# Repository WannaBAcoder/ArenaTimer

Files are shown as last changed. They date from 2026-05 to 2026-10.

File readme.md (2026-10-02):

# ⏱️ Event Match Timer & Lockout System

An open-source, ESP32-based event and match timer platform featuring wireless remote integration, with web interface.

---

## 🚀 Getting Started

### 1. Hardware Orientation & Powering
* **Orientation Flexibility:** The timer can be configured to operate in either horizontal orientation. If your mounting or power cable strategy requires it, you can flip the included hanging bracket to the opposite side and enable **Invert Display** in the web settings to route the power cable from above.
* **Power Requirements:** Connect the timer using the provided power supply. 
> ⚠️ **CRITICAL:** Only use **5V** power supplies capable of delivering at least **60W**. Applying a voltage higher than 5V will **permanently damage** the hardware.

### 2. Initial Wi-Fi & Web UI Setup
1. **Boot Sequence:** Upon power-up, the display initializes with dashes (`--:--`) and the border will blink, indicating it is attempting to connect to the last saved Wi-Fi network.
2. **Access Point (AP) Mode:** If the network is unavailable (or during first-time setup), the timer switches to AP mode, broadcasting its own network:
   * **SSID:** `TimerSetup`
   * **Password:** `12345678`
3. **Connecting to the UI:** * Connect your phone, tablet, or computer to the `TimerSetup` network.
   * Locate the timer's IP address in your device's network connection settings (this process varies by operating system).
   * Open a web browser and enter the IP address to access the control interface.

<p align="center">
  Web Control Interface Dashboard
</p>

*Note: The local AP interface is identical to the network interface. If no external Wi-Fi network is available at your venue, you can run the timer in this standalone mode completely offline.*

4. **Station Mode (Optional):** To connect the timer to an existing venue Wi-Fi network, use the configuration section at the bottom of the webpage to save your local **SSID** and **Password**.

<p align="center">
  Wireless Remotes Layout
</p>

---

## ⚙️ Configuration & Features

### 🎮 Wireless Remotes & Pairing
The system supports three battery-powered wireless remotes: **one Main Controller** and **two Driver Ready/Tap-Out buttons** (Red vs. Blue).

<p align="center">
  Wireless Remotes Layout
</p>

* **Pairing Procedure:** Remotes must be paired before deployment. Click **Pair Remote** in the Web UI to enter binding mode, turn on the remote, and press any button. The timer will automatically exit binding mode, and the Web UI status will update to `Paired`.  Repeat independently for each remote.
  * *Pairing Timeout:* Binding mode automatically cancels itself after 15 seconds if no remote responds (with a live countdown shown on screen), rather than hanging indefinitely until a reboot.
* **Driver Ready Lockout:** Enabling the `Require Driver Ready` checkbox prevents a match from starting until both driver remotes register a "Ready" state - the **Start** button itself grays out while waiting, and the ready state for each side is shown directly under the countdown.
  * *Visual Indicators:* The physical white border indicates overall readiness. Individual Red/Blue illumination confirms when each respective driver has ready-ed up.
* **Tap-Out Functionality:** Even if the pre-match lockout is disabled, the driver remotes function by default as tap-out indicators. Pressing them during a match triggers a unique tap-out animation and audio effect (can be toggled off via the checkbox).

<p align="center">
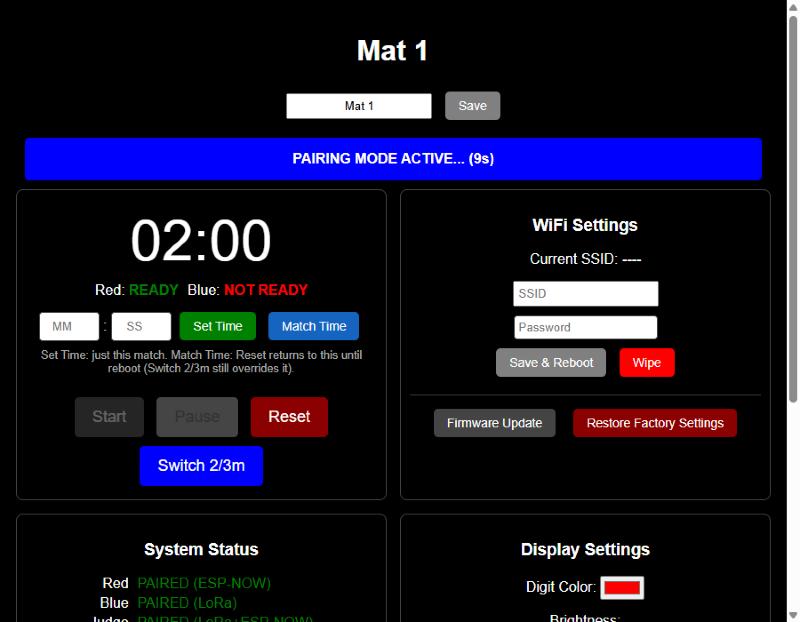
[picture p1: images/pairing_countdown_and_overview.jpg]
Pairing countdown, ready status, and per-timer naming
  
</p>

### 📻 ESP-NOW and LoRa Remotes, Side by Side
Newer timer boards carry an onboard LoRa radio alongside the original ESP-NOW remote support - both run **at the same time, in the same firmware image**. That means a single timer can have, say, Red paired to an older ESP-NOW remote while Blue and Judge are paired to newer LoRa remotes, so a LoRa-capable board can go into service before every remote in the field is replaced.

* **Per-Role Binding:** Each of Red, Blue, and Judge is paired independently, and the System Status panel shows exactly which radio each one is bound through - `PAIRED (ESP-NOW)`, `PAIRED (LoRa)`, or `PAIRED (LoRa+ESP-NOW)` if the same role has been bound on both.
* **Automatic Hardware Detection:** On boards without the LoRa radio installed, the firmware detects its absence at boot (shown as `LoRa radio: Not detected`) and simply runs ESP-NOW only, rather than wasting startup time retrying a radio that isn't there.

<p align="center">
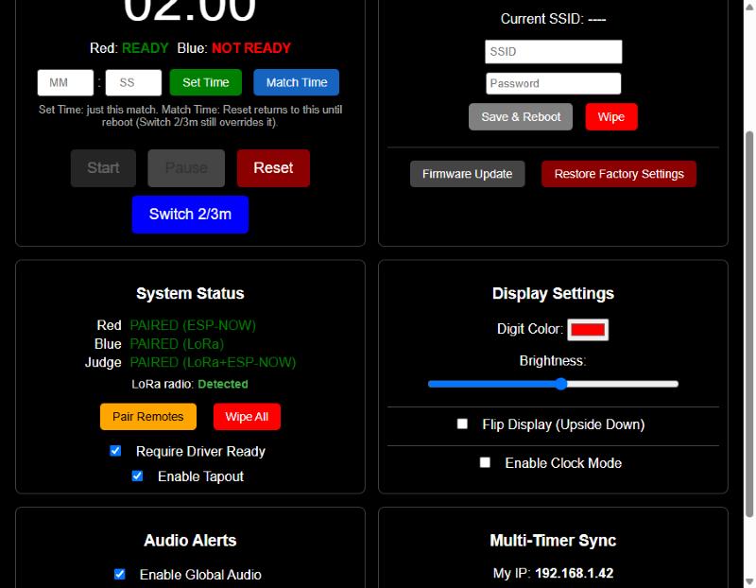
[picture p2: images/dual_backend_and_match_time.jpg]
Dual ESP-NOW/LoRa pairing status, Match Time, and WiFi management
  
</p>

### 🔗 Multi-Timer Sync (Web-Based)
Running several mats off one set of remotes already works by pairing the same remote to each timer directly (above) - but for anything triggered from the **web page** (start/pause/reset, time-select, colors, brightness, audio, ready/tapout settings), pair two timers together over WiFi so clicking a button on one applies to both.

* **Setup:** Open the **Multi-Timer Sync** panel, enter the other timer's local IP address (shown on its own page as `My IP`), and click **Sync**. Everything that timer currently has configured pushes over immediately, so both units start in agreement instead of drifting until the next change.
* **What Syncs:** Match control, match time, display color/brightness/flip, audio settings, ready-required, tap-out, and clock mode. Remote button presses are *not* relayed this way - they already reach every timer that remote is directly paired to, with no extra setup needed.
* **One-Directional by Default:** Sync only pushes outward from whichever timer's web page you clicked on - pair both timers to each other's IP if you want either one to be able to drive the other.
* **Naming Timers:** Give each unit a short label (e.g. "Mat 1") at the top of its page - shown in the browser tab too - so it's obvious which page you're looking at when several are open side by side.

### ⏱️ Match Time vs. Set Time
Two different buttons next to the manual MM:SS entry handle two different needs:

* **Set Time:** A one-off override for just the upcoming match. Pressing **Reset** afterward falls back to whatever the standing default already was (the 2/3-minute preset, or a previously-set Match Time).
* **Match Time:** Sets a new standing default - **Reset** keeps returning to this duration until the unit reboots (it isn't saved permanently, so a custom one-off event length doesn't silently become the new default forever). The **Switch 2/3m** button still overrides it either way.

### 🕐 Clock Mode
Toggle **Enable Clock Mode** (in Display Settings) to repurpose the digit display as a wall clock when the timer is idle between matches. The web page itself keeps showing whatever match time was last active (dimmed, since it isn't live) - the physical display is what shows the actual time.

### 🔊 Audio Options
* **Global Toggle:** Easily enable or disable all system audio via the web panel.
* **Output Routing:** Switch between the onboard piezo beeper or a dedicated **relay output** used to switch larger external horn circuits, PA systems, or specialized lighting.
* **Attention Horn:** The Main Controller features a dedicated button to manually trigger the sound effects to grab the attention of competitors or spectators.

### 🔒 Operational Lockout
To prevent accidental mid-match disruption, most configuration options, adjustments, and web buttons are **automatically disabled** while the timer is actively running.

---

## 🛠️ Assembly Process (Electronics Kits)

For users assembling the hardware from the DIY electronics kits, follow this general framework. Refer to the project `BOM.md` for exact hardware sizing, screw counts, and component sourcing links.

### 1. 3D Printed Frame Selection
Choose the frame variant that best fits your 3D printer's build volume:
* **Small Printers:** Cut down to fit standard build plates. Requires more assembly hardware and time but maximizes accessibility.
* **Medium Printers (H2s/H2d Optimized):** A balanced approach featuring lower part counts and optimized print times.
* **Large Printers:** Designed specifically for large-format platforms like the *Elegoo Orange Storm Giga*. 

### 2. Print Settings & Materials
* **Main Frame:** Print in **PETG** for superior mechanical strength and thermal resilience during high-temperature transport or storage.
  * **Walls:** 4–6 perimeters
  * **Infill:** 15–25% Gyroid
* **Lenses:** All frame variations share the same lens files. Print them with enough top/bottom layers to ensure the front face prints **completely solid** to optimize light diffusion and visual clarity.

---

## 🧠 Advanced Development & Limitations

### 📡 RF Limitations & Best Practices
The timer utilizes an **ESP32** module with a printed trace antenna; remotes utilize **ESP8266** modules over ESP-NOW, or on newer timer boards, dedicated **LoRa** radios (see [ESP-NOW and LoRa Remotes, Side by Side](#-esp-now-and-lora-remotes-side-by-side) above) - both with printed antennas.
* **Range & Interference:** While highly reliable in tested arena layouts (e.g., SEMO), performance can degrade at extreme distances or in environments experiencing heavy 2.4 GHz spectrum congestion (crowded Wi-Fi, heavy radio traffic).
* **Upgrades:** If your venue demands extreme range, the hardware can be modified to use variants featuring external SMA antennas. Reach out if you need assistance engineering a solution.
* **Running Multiple Timers:** Pair a single set of remotes to multiple timers by repeating the pairing process on each one (above), and/or bind timers to each other for web-triggered actions - see [Multi-Timer Sync](#-multi-timer-sync-web-based) above.

### 💻 Firmware Upgrades & Exposed I/O
* **Over-The-Air (OTA) Updates:** Firmware updates can be flashed seamlessly without opening the enclosure. Navigate to `http://<your-timer-ip>/update` to access the **ElegantOTA** interface, where you can drag-and-drop compiled `.bin` updates.
* **Restore Factory Settings:** A dedicated button wipes all remotes, WiFi credentials, sync target, and display/audio settings in one step, then reboots - useful for repurposing a unit or ruling out a stale setting during troubleshooting. WiFi credentials alone can also be wiped independently (`Wipe`, next to Save & Reboot) without touching anything else.
* **Hardware Expansion:** Additional I/O pins are deliberately exposed near the internal ESP32 module. Advanced users can open the case and solder directly to these lines to integrate custom addressable LED strips, sensors, or physical inputs.

### ⚡ ESD Precautions & LED Repair
> ⚡ **CAUTION:** The internal PCBs contain components sensitive to Electrostatic Discharge (ESD). Handle bare board assemblies with care during assembly or modifications.

* **Common Failure Mode:** If an ESD event occurs, a single addressable LED in the display chain may burn out. Because the LEDs are wired in series, **if one LED fails, all subsequent data down the chain is blocked**, causing the rest of the display past that point to drop out. 
* **Support:** If you experience an LED failure during assembly or firmware hacking, reach out—these are repairable, and I can guide you through jumping or replacing the compromised pixel. Note that failures have only occurred during loose bench development; fully enclosed units have proven resilient during regular live event usage.

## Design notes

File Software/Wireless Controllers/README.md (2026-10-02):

# Wireless Controllers

Remote-side firmware for the battle timer's two supported remote protocols.
A remote is one or the other - never both, and nothing else:

- **`ESPNOW_Remote/`** - genuine ESP-NOW (ESP8266, `espnow.h`), each a
  separate PlatformIO project (not variants of one shared source):
  - `controller/` - the Judge remote, 5 buttons.
  - `ready_remote/` - the Red/Blue "driver ready" remote, 1 button. Set
    `DEV_TYPE` to `"RedReady"` or `"BlueReady"` per physical unit before
    flashing. Recovered from git history (commit f13efa9) after a later
    commit overwrote this same filename with an unrelated LLCC68/RadioLib
    design that was never ESP-NOW at all.

  Both received by the timer's `espnowRemotes.cpp`.

- **`TimerRemote/`** - the correct, current LoRa remote (STM32 + RA-08H
  radio module, talks to the timer's own RA-08H over actual LoRa RF, not
  WiFi). Received by the timer's `loraRemotes.cpp`. This is the one to
  build on for any new LoRa remote work.

- **`_archive/`** - superseded prototypes, kept for reference only. Not
  wired up to anything current and safe to delete outright once nobody
  needs to look back at them:
  - `timer_wifi_logic/` - an early draft of the *timer's* own ESP-NOW
    receive logic, predating and superseded by `Software/main`'s
    `espnowRemotes.cpp`. Not a remote.

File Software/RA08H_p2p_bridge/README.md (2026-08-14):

# RA-08H P2P Bridge Firmware

Replacement firmware for the RA-08H (ASR6601) LoRa modules on the ArenaTimer
boards. The stock Ai-Thinker firmware is **LoRaWAN-only** (`release/v1.3.4
LoRaWAN for US915`) and has no device-to-device path — LoRaWAN requires a
gateway and network server, so it can't be used for remote-to-timer links.
This firmware replaces it with raw LoRa P2P.

It exposes the same text protocol the host code already speaks, so
`TimerRemote/src/radio.cpp` and `Software/main/src/loraRemotes.cpp` need no
changes:

```
host -> radio:  AT+TEST=TXLRPKT,"<HEX>"\n
radio -> host:  OK                                     (accepted, transmitting)
                ERROR                                  (bad command or payload)
                +TEST: RXLRPKT,"<HEX>",<rssi>,<snr>    (packet received)
```

Identical on both boards — which side is "remote" vs "timer" is purely a
host-MCU concern.

## Runtime RF config

TX power, spreading factor, bandwidth, and coding rate are adjustable at
runtime, so range/power tuning doesn't require reflashing the radio — only
the host MCU (much cheaper to reflash via SWD, no BOOT-jumper dance needed):

```
host -> radio:  AT+RFCFG=<power>,<sf>,<bw>,<cr>\n
radio -> host:  OK                                (applied)
                ERROR                              (out of range or malformed)

host -> radio:  AT+RFCFG?\n
radio -> host:  +RFCFG: <power>,<sf>,<bw>,<cr>
                OK
```

| field | range | meaning |
|---|---|---|
| power | -3 to 22 | dBm (SX1262's actual max is 22, not the 14 the defaults use) |
| sf | 5 to 12 | spreading factor |
| bw | 0, 1, 2 | 0 = 125 kHz, 1 = 250 kHz, 2 = 500 kHz |
| cr | 1 to 4 | coding rate, 1 = 4/5 ... 4 = 4/8 |

**Not persisted** — RFCFG changes are RAM-only and reset to the `DEFAULT_*`
values in `main.c` on every power-up/reset. The host is expected to re-send
its desired config (from its own persistent settings) after every boot; see
`TimerRemote/src/radio.cpp`'s `radioInit()` and `Software/main/src/loraRemotes.cpp`'s
`loraInit()` for where that happens.

Spreading factor and bandwidth must match on both ends of a link — the two
radios can't demodulate each other's packets otherwise. TX power is
one-sided and only needs to change on the transmitting radio.

## Runtime RX mode

Also adjustable at runtime: whether the radio sits in continuous receive or
sleeps between transmits. A LoRa remote in this system only ever sends
button presses and never needs to receive, so leaving it in continuous RX —
the SX1262's most power-hungry state — burns battery for no functional
benefit. The timer needs the opposite: it must always be listening.

```
host -> radio:  AT+RXMODE=<mode>\n
radio -> host:  OK                                (applied)
                ERROR                              (out of range or malformed)

host -> radio:  AT+RXMODE?\n
radio -> host:  +RXMODE: <mode>
                OK
```

| mode | meaning |
|---|---|
| 0 | TX-only — radio sleeps between sends, wakes automatically to transmit |
| 1 | continuous RX (default) — always listening, as before this command existed |

Same as RFCFG: not persisted, RAM-only, reset to `DEFAULT_RX_MODE` on every
power-up. Waking from sleep to transmit needs no special handling — any SPI
transaction wakes the SX1262 automatically (a documented hardware feature),
and this firmware already relies on that exact transition after every
completed TX regardless of RX mode.

Both host projects' `rfConfig.h` currently default to `RF_RX_MODE = 1`
(continuous, matching pre-RXMODE behavior) even on remotes, until TX-only
mode has been measured and validated on real hardware. Flip to `0` on a
remote's `rfConfig.h` once confirmed worthwhile, and reflash just that
board's STM32/ESP32 — no radio reflash needed, same firmware image runs
either mode.

## Radio configuration (power-on defaults)

| setting | value |
|---|---|
| frequency | 915 MHz (US915) |
| spreading factor | SF7 |
| bandwidth | 125 kHz |
| coding rate | 4/5 |
| TX power | 14 dBm |
| preamble | 8 symbols |
| max payload | 32 bytes |

## UART wiring

Two different UART peripherals are used, matching how the stock firmware did
it and matching the board's existing traces:

- **LPUART RX** — GPIOD pin 12 (`LPRXD`/IO60), commands arrive from the host MCU
- **UART0 TX** — GPIOB pin 1 (`TXD`/IO17), responses go out; shared with the
  flash/debug port

Both at **9600 baud**. This is a hardware limit, not a preference: the AT
interface runs on the LPUART, whose baud rate cannot exceed 9600.

## Building

Needs the Ai-Thinker SDK (`Ai-Thinker-Open/Ai-Thinker-LoRaWAN-Ra-08`). Drop
this directory in as `projects/ASR6601CB-EVAL/examples/lora/p2p_bridge`, then
from Git Bash:

```bash
export TREMO_SDK_PATH=/path/to/Ai-Thinker-LoRaWAN-Ra-08
export PATH="$PATH:$HOME/.platformio/packages/toolchain-gccarmnoneeabi/bin:/c/ProgramData/chocolatey/bin"
make
```

No WSL required — PlatformIO's bundled `toolchain-gccarmnoneeabi` (xPack GNU
Arm Embedded GCC) plus chocolatey's `make` build it natively on Windows, which
is what the SDK's own `envsetup.sh` falls back to when `arm-none-eabi-gcc` is
already on PATH.

A prebuilt `p2p_bridge.bin` is included.

## Flashing

The RA-08H enters download mode when **BOOT (IO2, module pin 15) is high at
reset**. On these boards that pad is tied to GND by the JP1 solder jumper, so:

1. Cut the JP1 bridge, wire that pad to VCC (needs a pullup — a bare floating
   wire is not enough).
2. Power-cycle the board.
3. Flash — the adapter's RX taps the existing `TXD` trace, no bodge needed:

```bash
python $TREMO_SDK_PATH/build/scripts/tremo_loader.py -p COM16 -b 921600 flash 0x08000000 p2p_bridge.bin
```

4. Return BOOT to GND and power-cycle again for normal boot.

Future board revisions should provision a proper programming header — doing
this by hand does not scale past a handful of boards.

## Debugging note

**Start the serial listener _before_ power-cycling the board.** This firmware
prints its boot log once and then goes quiet, so a listener attached a few
seconds later sees nothing and looks identical to a dead board. That false
signal cost a long debugging detour; `uart_probe`-style firmware that prints
in a loop is not affected, which makes the contrast misleading.

Expected boot output:

```
=== p2p_bridge boot ===
CKPT: xo32k enabled
... (per-step init checkpoints) ...
CKPT: rf config applied (power=14 sf=7 bw=0 cr=1)
READY
```

`READY` means the radio is initialized and listening.

## Verified

Bench test, two boards a few inches apart, 3/3 packets received intact at
RSSI −5 dBm / SNR 13 dB.

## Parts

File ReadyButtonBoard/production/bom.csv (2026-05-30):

Designator | Footprint | Quantity | Value | LCSC Part #
D1 | 0603 | 1 | Red | C2286
J1, J2 | PinSocket_1x08_P2.54mm_Vertical | 2 | Conn_01x08_Socket | C42431840
J9 | 2060-452_998-404 | 1 | WAGO | C2765055
R1 | 0603 | 1 | 470 | C23179
SW1 | SW_PUSH-12mm | 1 | START | C2888699

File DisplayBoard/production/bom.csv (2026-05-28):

Designator | Footprint | Quantity | Value | LCSC Part #
C1, C2, C3, C4, C5, C6, C7 | 0402 | 7 | 100nF | C14663
D1, D10, D11, D112, D113, D114, D115, D116, D117, D118, D12, D13, D14, D15, D154, D155, D156, D157, D158, D159, D16, D160, D17, D18, D19, D2, D20, D21, D22, D23, D238, D239, D24, D240, D241, D242, D243, D244, D245, D246, D247, D248, D249, D25, D250, D251, D252, D253, D254, D255, D256, D257, D258, D259, D26, D260, D261, D262, D263, D264, D265, D266, D267, D268, D269, D27, D270, D271, D272, D273, D274, D275, D276, D277, D278, D279, D28, D280, D281, D282, D283, D284, D285, D286, D287, D288, D289, D29, D290, D291, D292, D293, D294, D295, D296, D297, D298, D299, D3, D30, D300, D301, D302, D303, D304, D305, D306, D307, D308, D309, D31, D310, D311, D312, D313, D314, D315, D316, D317, D318, D319, D32, D320, D321, D322, D323, D324, D325, D326, D327, D328, D329, D33, D330, D331, D332, D333, D334, D335, D336, D337, D338, D339, D34, D340, D341, D342, D35, D36, D37, D38, D4, D5, D6, D7, D70, D71, D72, D73, D74, D75, D76, D77, D78, D79, D8, D80, D81, D82, D83, D9 | LED_WS2812B_PLCC4_5.0x5.0mm_P3.2mm | 171 | WS2812B | C2843785
D40 | D_SMA | 1 | 1N1007, SMA | C727081
D41 | D_SOD-323 | 1 | 1N4148WS, SOD323 | C2128
J1 | JST_EH_S2B-EH_1x02_P2.50mm_Horizontal | 1 | Blue ready-up | C19271377
J10 | JST_EH_S2B-EH_1x02_P2.50mm_Horizontal | 1 | Red ready-up | C19271377
J13, J14 | 2060-452_998-404 | 2 | WAGO | C2765055
J15, J16 | PinSocket_1x15_P2.54mm_Vertical | 2 | Conn_01x15_Socket | C124408
J2 | PinSocket_1x02_P2.54mm_Horizontal | 1 | Conn_01x02_Socket | C2897384
J3 | PinHeader_1x02_P2.54mm_Horizontal | 1 | Conn_01x02_Pin | C492410
J4 | PinHeader_1x04_P2.54mm_Horizontal | 1 | GND | C492412
J5 | PinHeader_1x04_P2.54mm_Horizontal | 1 | 5V | C492412
J6 | PinSocket_1x04_P2.54mm_Horizontal | 1 | GND | C2897386
J7 | PinSocket_1x04_P2.54mm_Horizontal | 1 | 5V | C2897386
J9 | JST_EH_S6B-EH_1x06_P2.50mm_Horizontal | 1 | Conn_01x06_Pin | C157919
Q1, Q2 | SOT-323_SC-70 | 2 | BSS138 | C5224267
R10, R2 | 0402 | 2 | 100K | C25530
R3, R4, R5, R6, R7, R8, R9 | 0402 | 7 | 10k | C25744

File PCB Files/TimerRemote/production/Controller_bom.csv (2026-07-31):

Designator | Footprint | Quantity | Value | LCSC Part #
C16 | 0402 | 1 | C | DNU
C17 | 0402 | 1 | 4.7pF | C1569
C18 | 0402 | 1 | 2pF | C1558
C24, C27 | 0402 | 2 | 1uF, 25V | C52923
C3, C5 | 0603 | 2 | 10uF, 25V | C96446
C4, C6, C8 | 0402 | 3 | 100nF | C1525
J13 | 2060-452_998-404 | 1 | WAGO | C2765055
J2 | Harwin_M20-89006xx_1x06_P2.54mm_Horizontal | 1 | PROG | C20610215
J3 | PinHeader_1x03_P2.54mm_Vertical | 1 | VBAT
J5 | PinHeader_1x03_P2.54mm_Vertical | 1 | GND
JP1 | SolderJumper-2_P1.3mm_Bridged_RoundedPad1.0x1.5mm | 1 | Jumper_2_Bridged
R19 | 0402 | 1 | 10k, 1% | C25744
R5, R6 | 0402 | 2 | 0 ohm | C17168
SW1 | SW_Push_1P1T_NO_CK_PTS125Sx43SMTR | 1 | START | C18186488
SW2 | SW_Push_1P1T_NO_CK_PTS125Sx43SMTR | 1 | PAUSE | C18186488
SW3 | SW_Push_1P1T_NO_CK_PTS125Sx43SMTR | 1 | RESET | C18186488
SW4 | SW_Push_1P1T_NO_CK_PTS125Sx43SMTR | 1 | TIME_SEL | C18186488
SW5, SW6 | SW_Push_1P1T_NO_CK_PTS125Sx43SMTR | 2 | BUZZER | C18186488
SW7 | SW_Slide_SPDT_Angled_CK_OS102011MA1Q | 1 | SW_SPDT | C136722
SW8 | SW_Push_1P1T_XKB_TS-1187A | 1 | SW_Push | C318884
U1 | RA-08H | 1 | Ai-Thinker RA-08H | C2991932
U2 | LQFP-32_7x7mm_P0.8mm | 1 | STM32G030K6Tx | C529331
U5 | SOT-23-5 | 1 | AP2112K-3.3 | C51118

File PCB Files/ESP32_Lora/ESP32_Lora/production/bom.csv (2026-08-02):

Designator | Footprint | Quantity | Value | LCSC Part #
C10, C11, C12, C13, C6, C8 | 0402 | 6 | 100nF | C1525
C14, C15, C5, C7, C9 | 0603 | 5 | 10uF, 25V | C96446
C16 | 0402 | 1 | C | DNU
C17 | 0402 | 1 | 4.7pF | C1569
C18 | 0402 | 1 | 2pF | C1558
D1 | D_SOD-323 | 1 | BAT760-7 | C124187
D10 | 0603 | 1 | LED, Red | C965799
D12 | 0603 | 1 | LED, Blue | C965807
J114 | USB_C_Receptacle_GCT_USB4105-xx-A_16P_TopMnt_Horizontal | 1 | USB_C_Receptacle_USB2.0_14P | C309347
J15, J16 | PinHeader_1x15_P2.54mm_Vertical | 2 | Conn_01x15_Socket | C7501269
J2 | U.FL_Molex_MCRF_73412-0110_Vertical | 1 | Conn_Coaxial_Small | C2987682
JP1 | SolderJumper-2_P1.3mm_Bridged_RoundedPad1.0x1.5mm | 1 | Jumper_2_Bridged
Q1, Q2 | SOT-23 | 2 | SS8050 | C2834467
R10, R14, R15, R16, R17 | 0402 | 5 | 10k | C25744
R104, R105 | 0201 | 2 | 5.1K | C367648
R11 | 0402 | 1 | 47.5K (1%) | C2930010
R12, R18 | 0402 | 2 | 470, 1% | C25117
R13 | 0402 | 1 | 22.1K (1%) | C43473
R5, R6 | 0402 | 2 | 0 ohm | C17168
SW1, SW2 | SW_Push_SPST_NO_Alps_SKRK | 2 | SW_Push | C115357
U1 | RA-08H | 1 | Ai-Thinker RA-08H | C2991932
U3 | QFN-28-1EP_5x5mm_P0.5mm_EP3.35x3.35mm | 1 | CP2102N-Axx-xQFN28 | C964632
U4 | ESP32-WROOM-32UE | 1 | ESP32-WROOM-32UE | C701344
U5 | SOT-23-5 | 1 | AP2112K-3.3 | C51118
U902 | SOT-143 | 1 | CM1213A−02Sx | C19268160

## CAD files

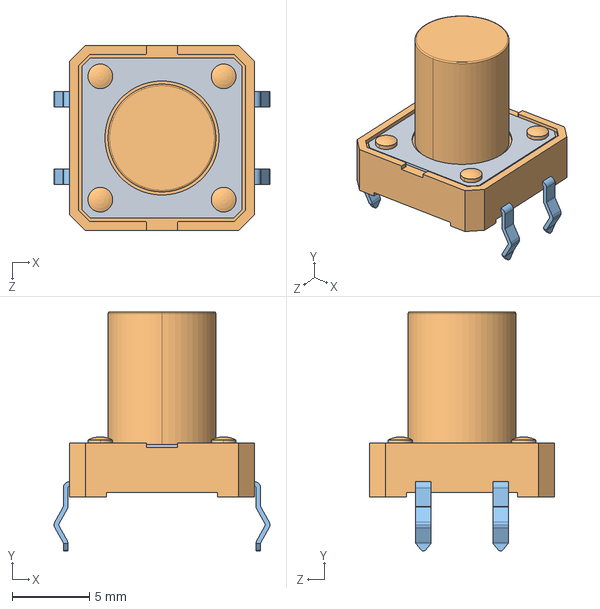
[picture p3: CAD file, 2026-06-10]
ButtonBoard/Same_Sky_TS14-1212-120-BK-260-SCR-D.step
14.0 x 15.5 x 12.0 mm

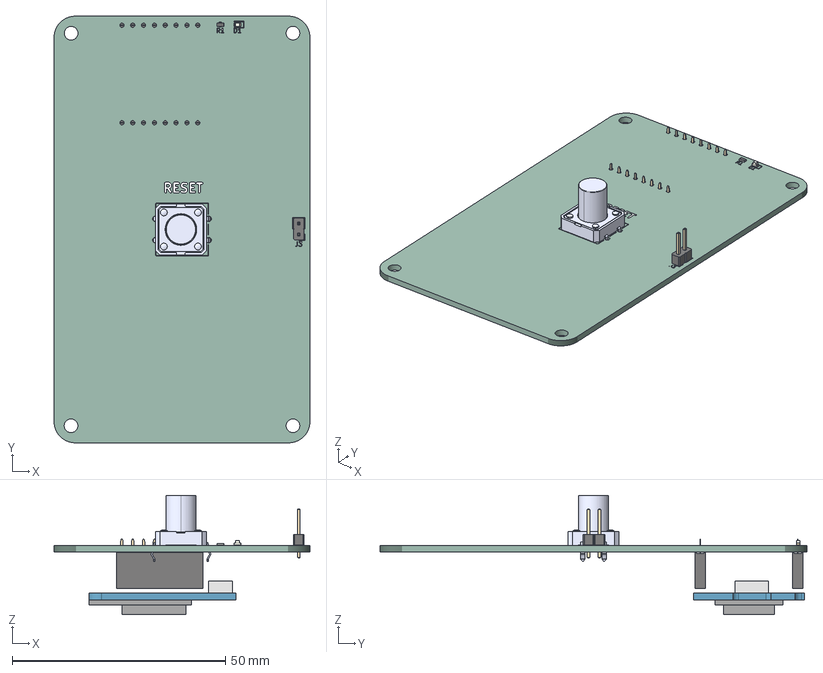
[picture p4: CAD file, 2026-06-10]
ReadyButtonBoard/ReadyButtonBoard.step
60.0 x 100.0 x 28.0 mm
PinHeader_1x02_P254mm_Vertical
LED_0603_1608Metric
CUI_DEVICES_TS14-1212-120-BK-260-SCR-D
R_0603_1608Metric
PinSocket_1x08_P2.54mm_Vertical x 2
wemos_d1_mini_light
ReadyButtonBoard_silkscreen x 2
ReadyButtonBoard_PCB

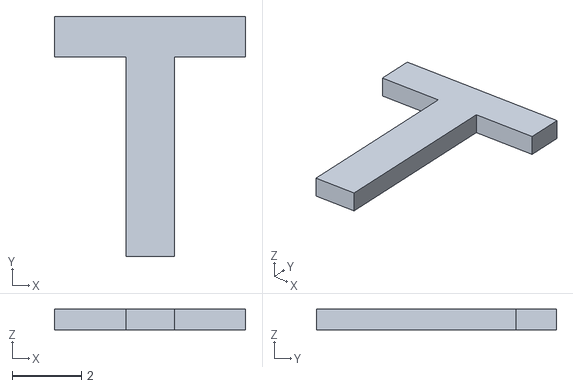
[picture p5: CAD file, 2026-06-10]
STLs/TimerPrints/Button Cases/ControllerHousing/ControllerHousing_ButtonBoard v22_Body22.stl
5.52 x 6.94 x 0.6

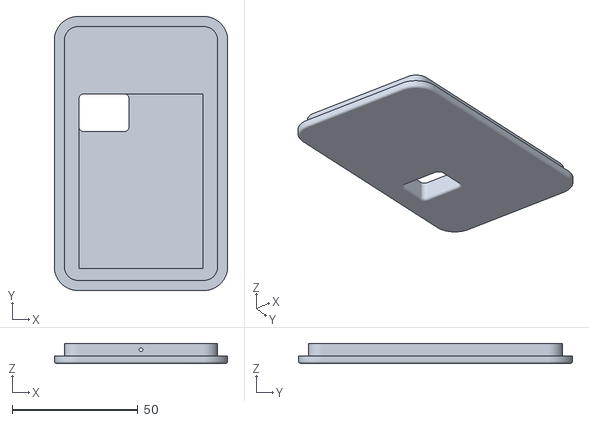
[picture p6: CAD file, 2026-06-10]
STLs/TimerPrints/Button Cases/ReadyButtonHousing/ReadyButtonHousing_LargerReadyButton v7_bottom_cover.stl
69.0 x 109.0 x 8.00

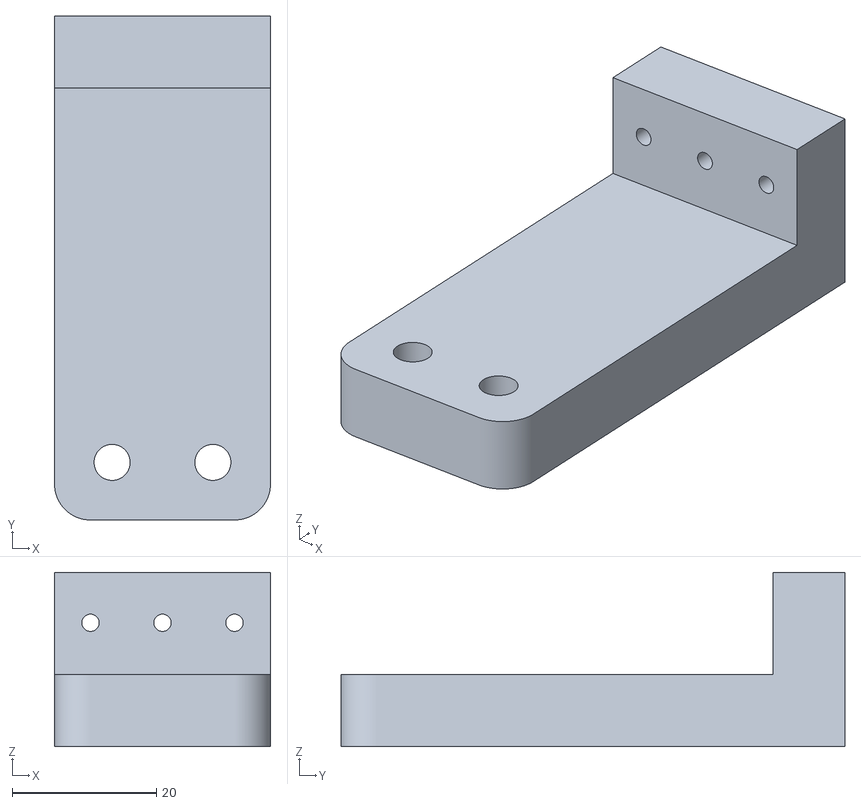
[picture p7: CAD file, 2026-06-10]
STLs/TimerPrints/Multi-Piece Housing/Hanging_mount.stl
30.0 x 70.0 x 24.2

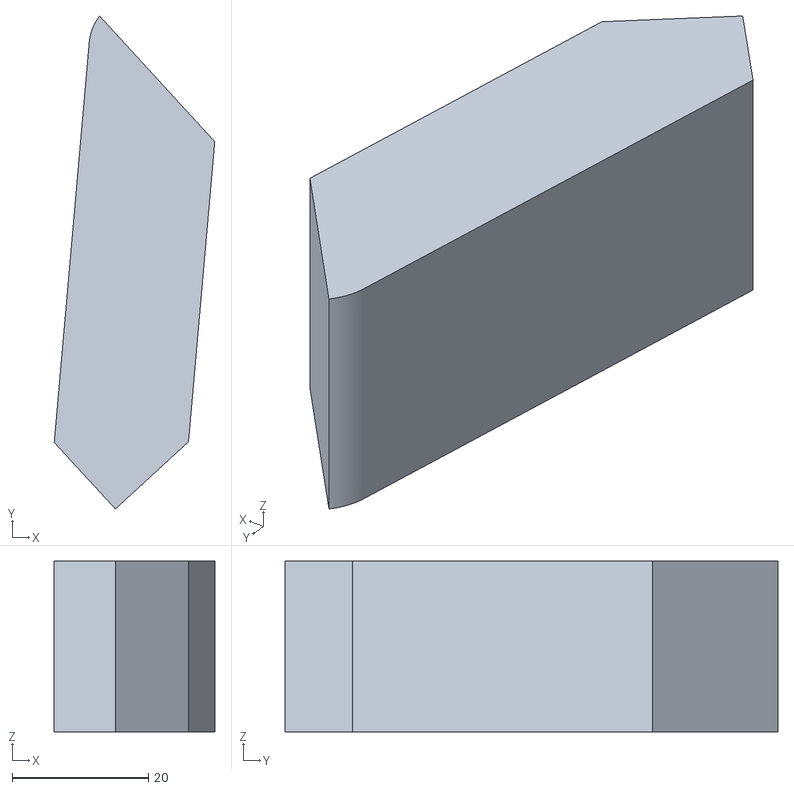
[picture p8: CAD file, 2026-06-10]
STLs/TimerPrints/Multi-Piece Housing/Lenses/seg_c.stl
23.5 x 72.3 x 25.0

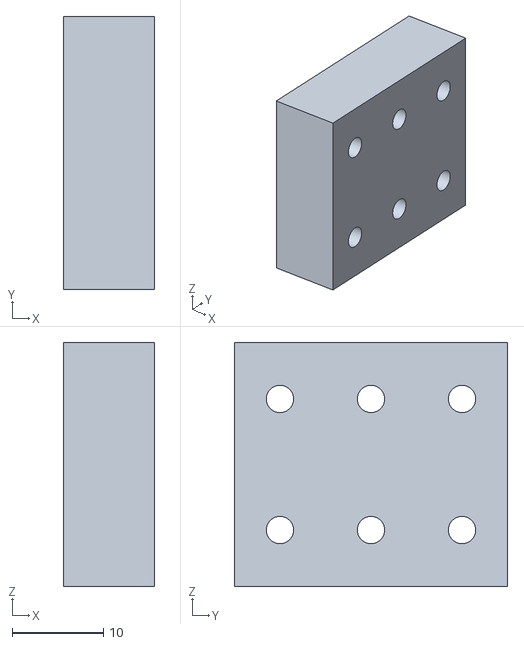
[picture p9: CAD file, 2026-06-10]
STLs/TimerPrints/Single Piece Housing/Double_sided_mount.stl
10.00 x 30.0 x 26.8

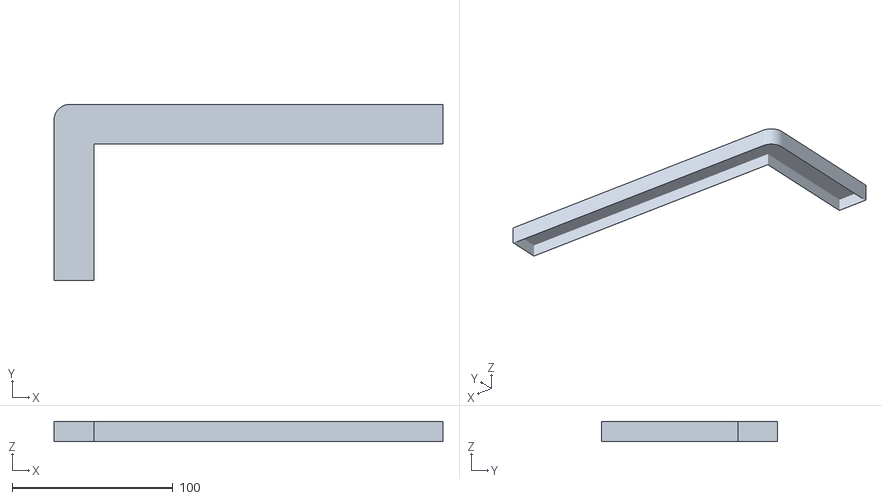
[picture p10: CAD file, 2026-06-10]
STLs/TimerPrints/Single Piece Housing/Lenses/bottom_right.stl
242.1 x 109.8 x 12.5

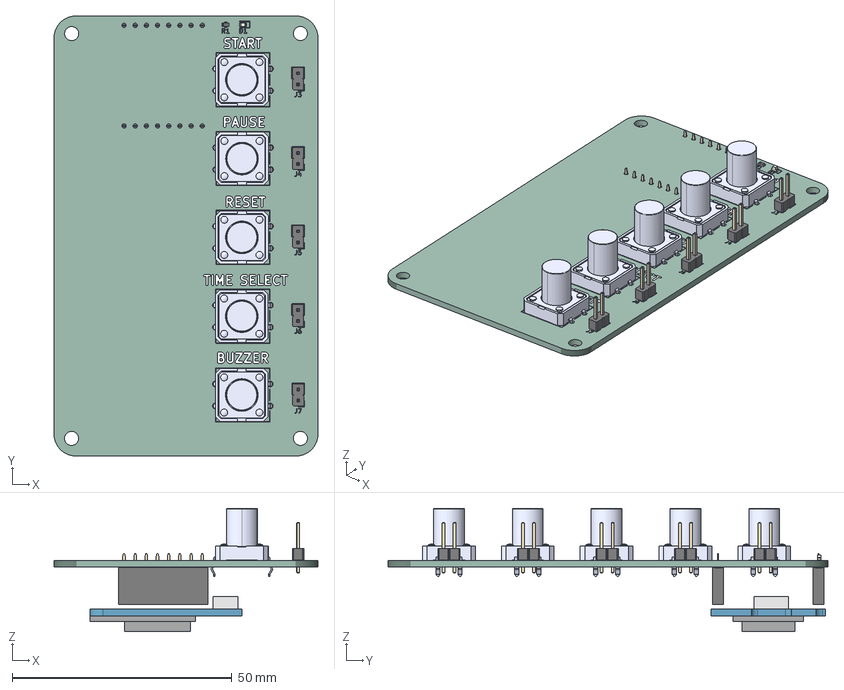
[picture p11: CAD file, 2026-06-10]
ButtonBoard/ButtonBoard.step
60.0 x 100.0 x 28.0 mm
PinHeader_1x02_P254mm_Vertical x 5
CUI_DEVICES_TS14-1212-120-BK-260-SCR-D x 5
LED_0603_1608Metric
R_0603_1608Metric
PinSocket_1x08_P2.54mm_Vertical x 2
wemos_d1_mini_light
ButtonBoard_silkscreen x 2
ButtonBoard_PCB

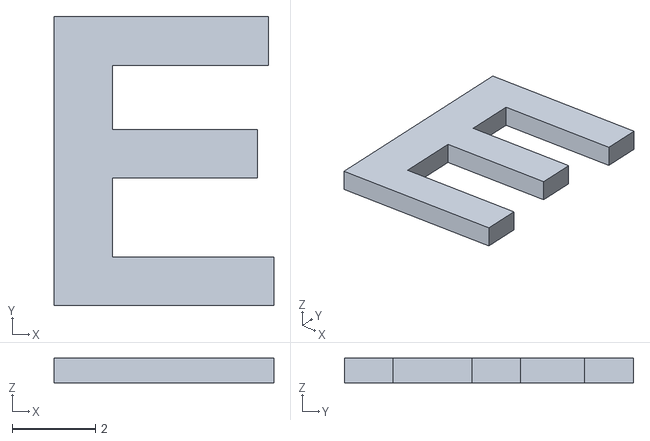
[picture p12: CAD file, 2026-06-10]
STLs/TimerPrints/Button Cases/ControllerHousing/ControllerHousing_ButtonBoard v22_Body16.stl
5.28 x 6.94 x 0.6

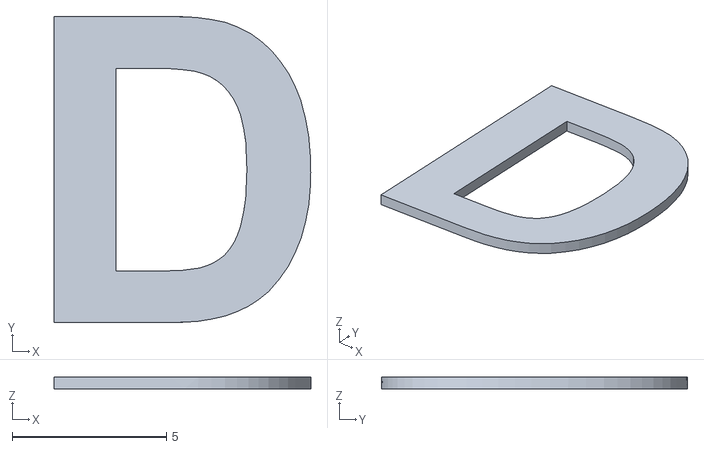
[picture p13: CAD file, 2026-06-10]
STLs/TimerPrints/Button Cases/ReadyButtonHousing/ReadyButtonHousing_LargerReadyButton v7_Body11.stl
8.32 x 9.92 x 0.4

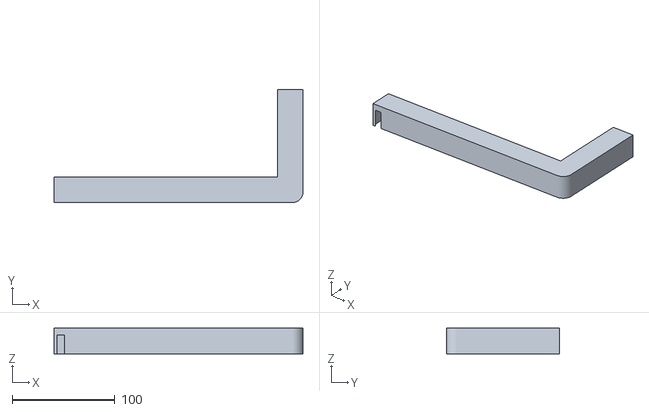
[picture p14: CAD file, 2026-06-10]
STLs/TimerPrints/Multi-Piece Housing/Lenses/Top_left_lens.stl
242.2 x 109.9 x 25.0

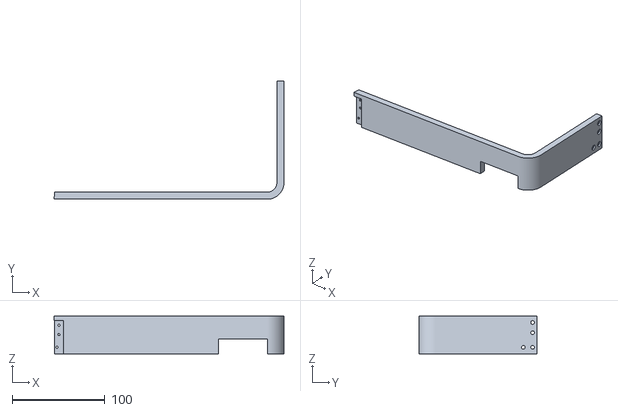
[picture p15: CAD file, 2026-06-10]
STLs/TimerPrints/Multi-Piece Housing/Top_left.stl
248.6 x 128.0 x 41.0

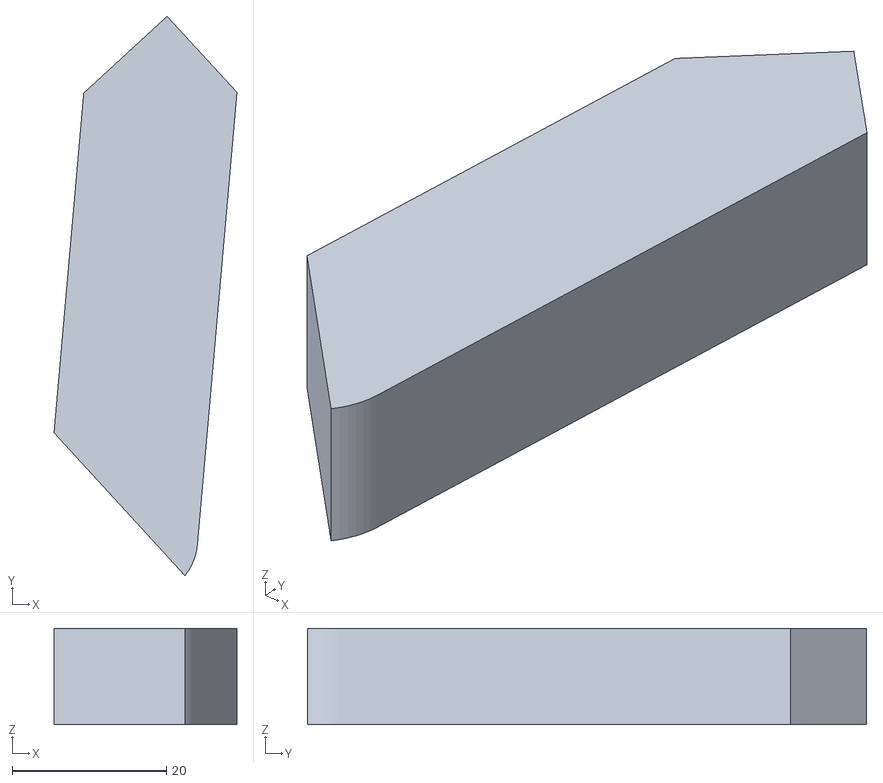
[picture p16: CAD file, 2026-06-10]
STLs/TimerPrints/Single Piece Housing/Lenses/seg_f.stl
23.7 x 72.6 x 12.5

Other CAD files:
STLs/TimerPrints/Button Cases/ControllerHousing/ControllerHousing_ButtonBoard v22_Body14.stl
STLs/TimerPrints/Button Cases/ReadyButtonHousing/ReadyButtonHousing_LargerReadyButton v7_Body10.stl
STLs/TimerPrints/Multi-Piece Housing/Bottom_right.stl
STLs/TimerPrints/Multi-Piece Housing/Lenses/seg_a.stl
STLs/TimerPrints/Button Cases/ControllerHousing/ControllerHousing_ButtonBoard v22_Body10.stl
STLs/TimerPrints/Button Cases/ControllerHousing/ControllerHousing_ButtonBoard v22_Body11.stl
STLs/TimerPrints/Button Cases/ControllerHousing/ControllerHousing_ButtonBoard v22_Body12.stl
STLs/TimerPrints/Button Cases/ControllerHousing/ControllerHousing_ButtonBoard v22_Body13.stl
STLs/TimerPrints/Button Cases/ControllerHousing/ControllerHousing_ButtonBoard v22_Body15.stl
STLs/TimerPrints/Button Cases/ControllerHousing/ControllerHousing_ButtonBoard v22_Body17.stl
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

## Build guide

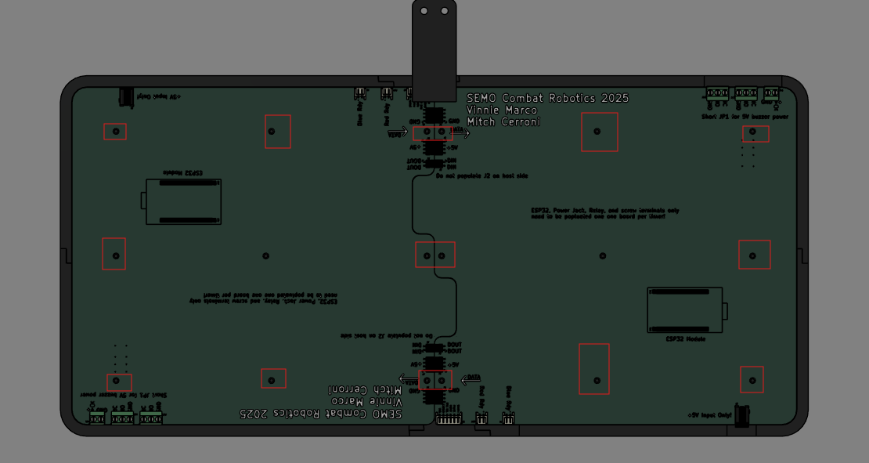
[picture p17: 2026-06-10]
STLs/TimerPrints/Multi-Piece Housing/Assembly/img2.png

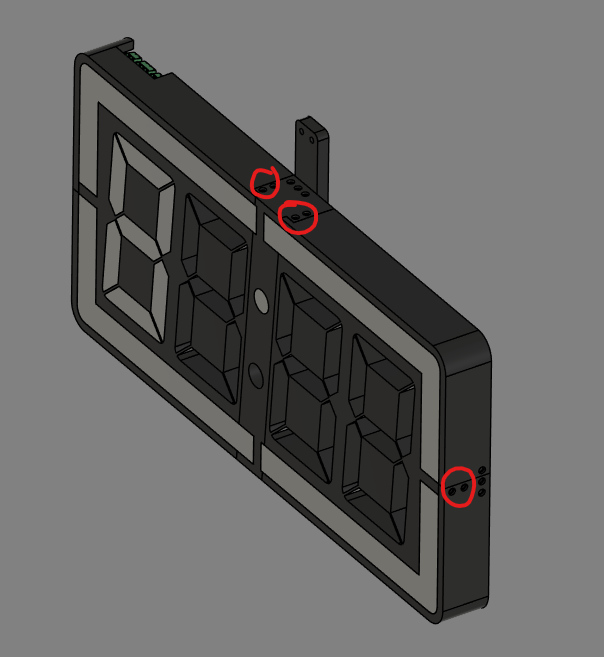
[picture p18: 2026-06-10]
STLs/TimerPrints/Multi-Piece Housing/Assembly/img3.png

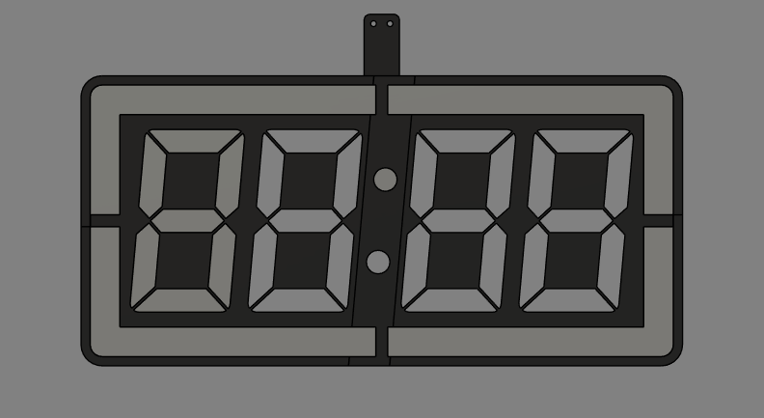
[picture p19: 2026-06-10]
STLs/TimerPrints/Multi-Piece Housing/Assembly/img1.png

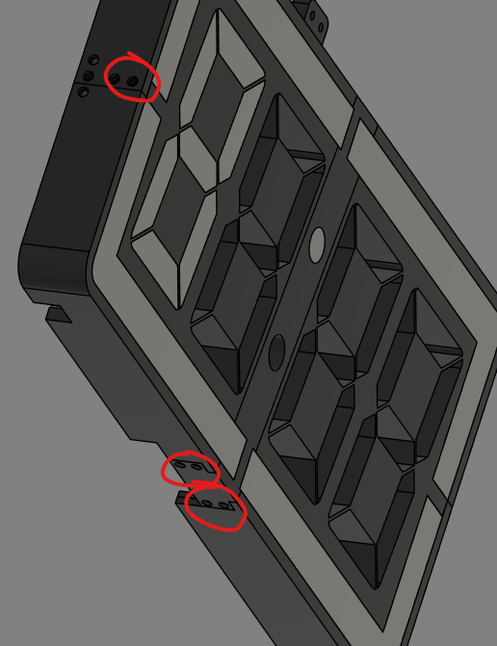
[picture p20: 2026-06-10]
STLs/TimerPrints/Multi-Piece Housing/Assembly/img4.png

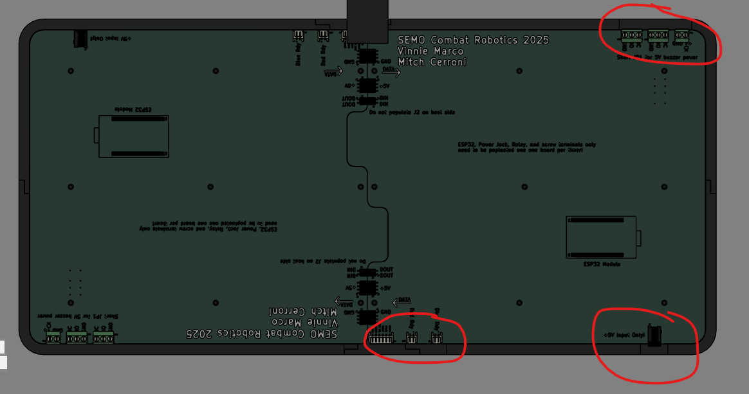
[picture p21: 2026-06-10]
STLs/TimerPrints/Multi-Piece Housing/Assembly/img5.png

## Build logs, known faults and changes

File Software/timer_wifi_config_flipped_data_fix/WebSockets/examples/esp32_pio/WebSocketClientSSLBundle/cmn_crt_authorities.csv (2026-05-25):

Owner | Common Name or Certificate Name
Amazon Trust Services | Amazon Root CA 1
Amazon Trust Services | Amazon Root CA 2
Amazon Trust Services | Amazon Root CA 3
Amazon Trust Services | Amazon Root CA 4
Amazon Trust Services | Starfield Services Root Certificate Authority - G2
DigiCert | Baltimore CyberTrust Root
DigiCert | Cybertrust Global Root
DigiCert | DigiCert Assured ID Root CA
DigiCert | DigiCert Assured ID Root G2
DigiCert | DigiCert Assured ID Root G3
DigiCert | DigiCert Global Root CA
DigiCert | DigiCert Global Root G2
DigiCert | DigiCert Global Root G3
DigiCert | DigiCert High Assurance EV Root CA
DigiCert | DigiCert Trusted Root G4
GlobalSign | GlobalSign ECC Root CA - R5
GlobalSign | GlobalSign Root CA - R3
GlobalSign | GlobalSign Root CA - R6
GlobalSign | GlobalSign Root CA
GoDaddy | Go Daddy Class 2 CA
GoDaddy | Go Daddy Root Certificate Authority - G2
GoDaddy | Starfield Class 2 CA
GoDaddy | Starfield Root Certificate Authority - G2
Google Trust Services LLC (GTS) | GlobalSign ECC Root CA - R4
Google Trust Services LLC (GTS) | GlobalSign Root CA - R2
Google Trust Services LLC (GTS) | GTS Root R1
Google Trust Services LLC (GTS) | GTS Root R2
Google Trust Services LLC (GTS) | GTS Root R3
Google Trust Services LLC (GTS) | GTS Root R4
IdenTrust Services, LLC | DST Root CA X3
IdenTrust Services, LLC | IdenTrust Commercial Root CA 1
IdenTrust Services, LLC | IdenTrust Public Sector Root CA 1
Sectigo | Comodo AAA Services root
Sectigo | COMODO Certification Authority
Sectigo | COMODO ECC Certification Authority
Sectigo | COMODO RSA Certification Authority
Sectigo | USERTrust ECC Certification Authority
Sectigo | USERTrust RSA Certification Authority

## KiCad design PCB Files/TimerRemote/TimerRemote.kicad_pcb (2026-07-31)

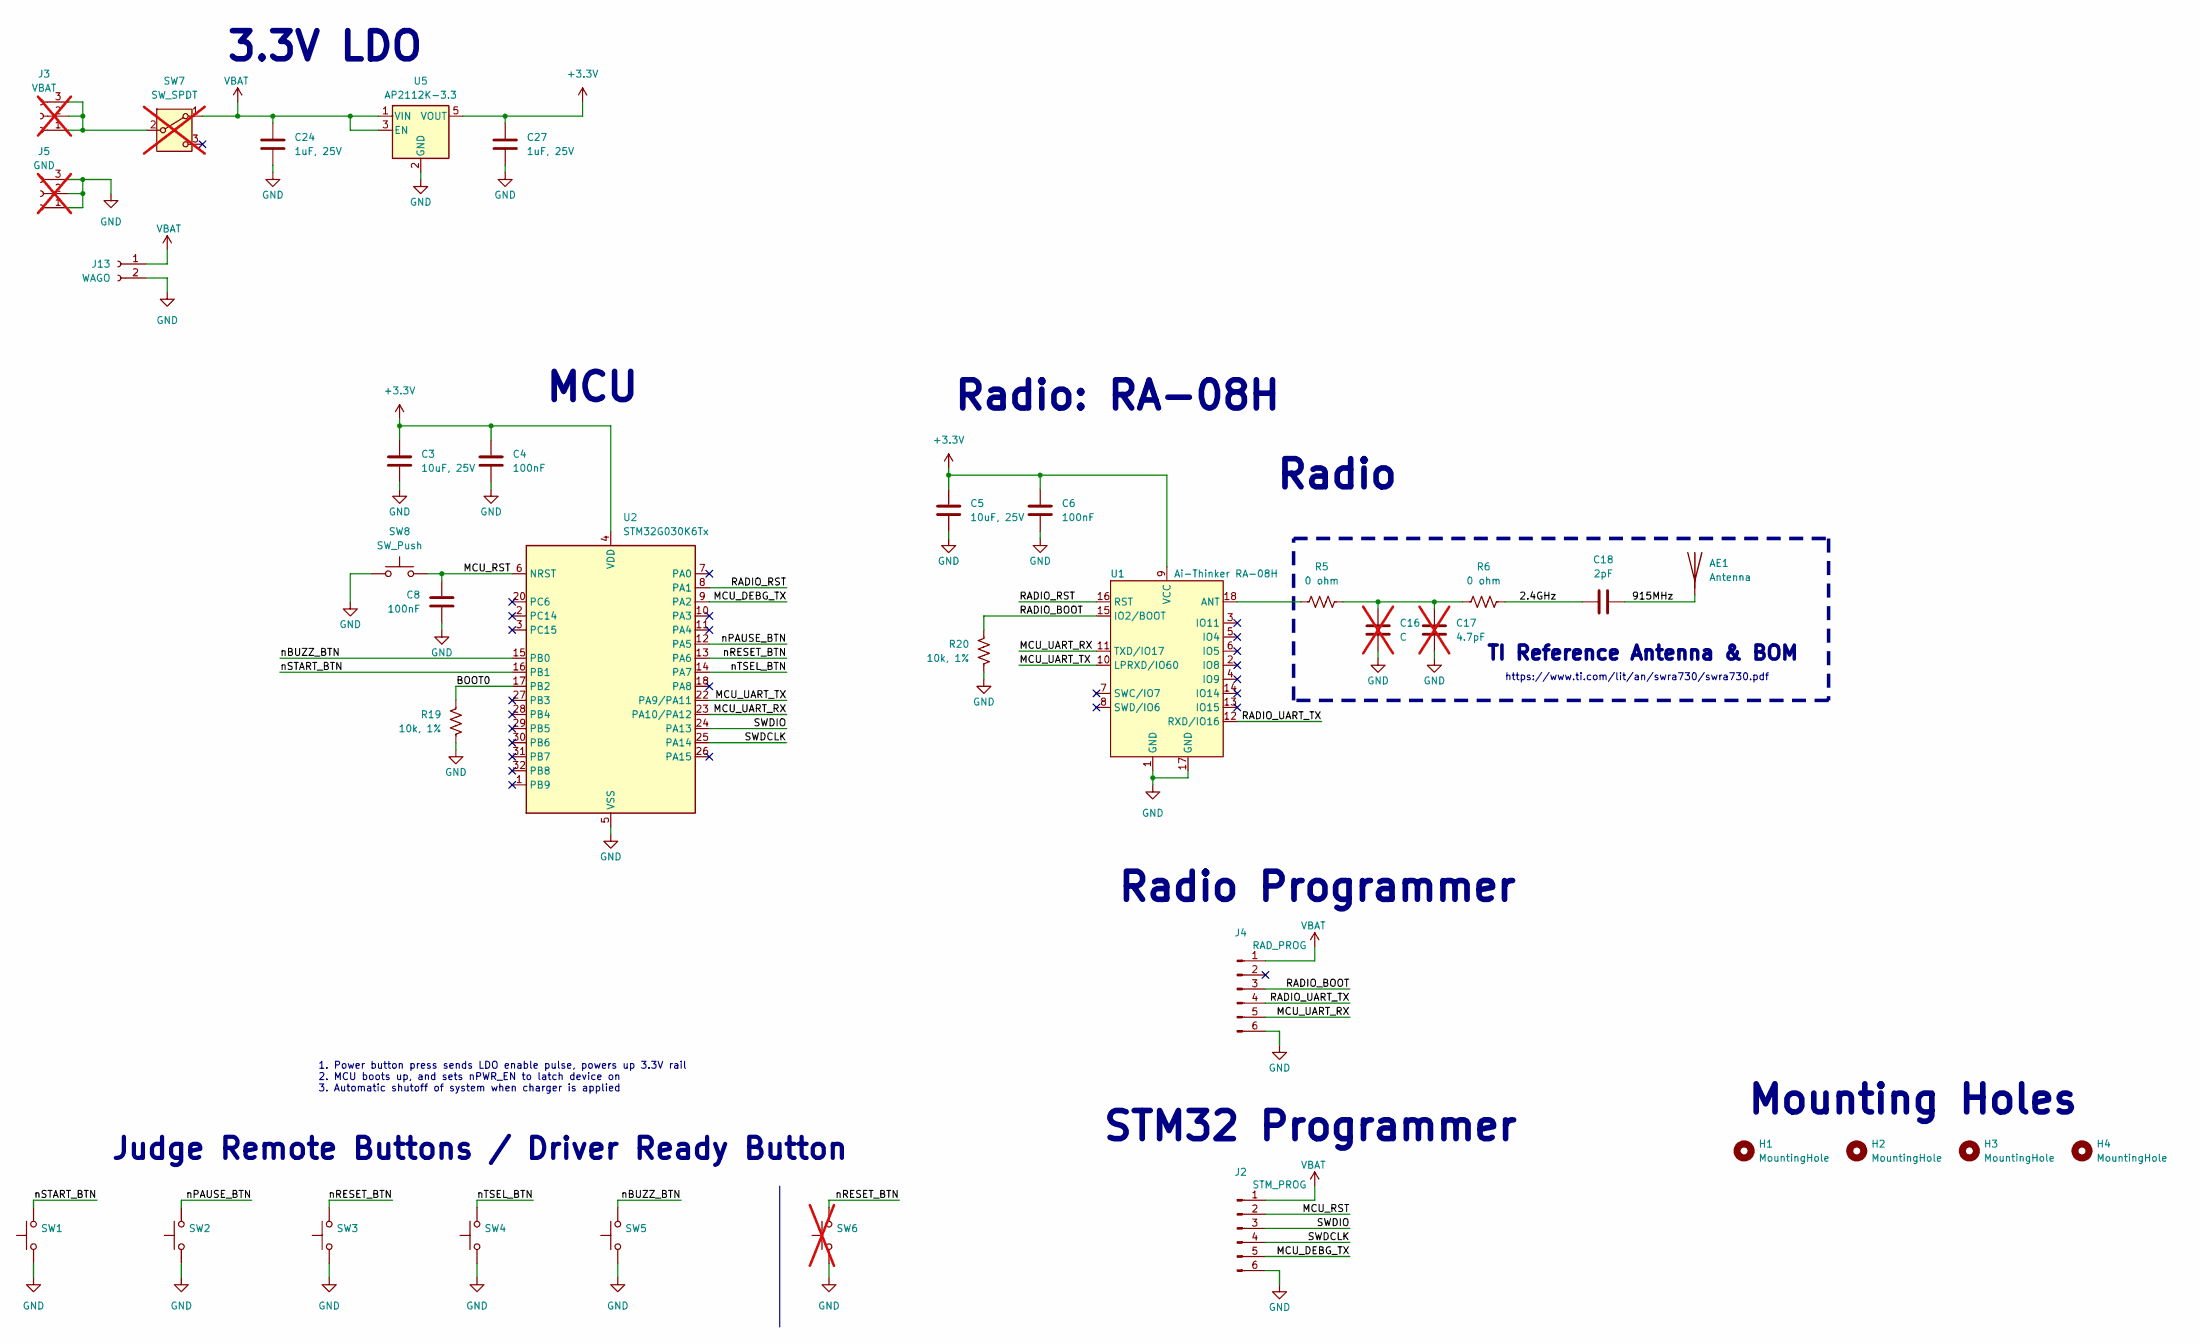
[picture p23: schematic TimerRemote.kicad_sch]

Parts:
AE1: Antenna
C3, C5: 10uF, 25V; C_0603_1608Metric; LCSC C96446
C4, C6, C8: 100nF; C_0402_1005Metric; LCSC C1525
C16: C; C_0402_1005Metric; LCSC DNU; not fitted
C17: 4.7pF; C_0402_1005Metric; MPN GRM0335C1H4R3CA01; LCSC C1569; not fitted
C18: 2pF; C_0402_1005Metric; LCSC C1558
C24, C27: 1uF, 25V; C_0402_1005Metric; LCSC C52923
H1, H2, H3, H4: MountingHole; MountingHole_3.2mm_M3
J2: STM_PROG; Harwin_M20-89006xx_1x06_P2.54mm_Horizontal; LCSC C20610215
J3: VBAT; PinHeader_1x03_P2.54mm_Vertical; not fitted
J4: RAD_PROG; Harwin_M20-89006xx_1x06_P2.54mm_Horizontal; LCSC C20610215
J5: GND; PinHeader_1x03_P2.54mm_Vertical; not fitted
J13: WAGO; 2060-452_998-404; LCSC C2765055
R5, R6: 0 ohm; R_0402_1005Metric; LCSC C17168
R19, R20: 10k, 1%; R_0402_1005Metric; LCSC C25744
SW1: START; SW_Push_1P1T_NO_CK_PTS125Sx43SMTR; LCSC C18186488
SW2: PAUSE; SW_Push_1P1T_NO_CK_PTS125Sx43SMTR; LCSC C18186488
SW3: RESET; SW_Push_1P1T_NO_CK_PTS125Sx43SMTR; LCSC C18186488
SW4: TIME_SEL; SW_Push_1P1T_NO_CK_PTS125Sx43SMTR; LCSC C18186488
SW5: BUZZER; SW_Push_1P1T_NO_CK_PTS125Sx43SMTR; LCSC C18186488
SW6: BUZZER; SW_Push_1P1T_NO_CK_PTS125Sx43SMTR; LCSC C18186488; not fitted
SW7: SW_SPDT; SW_Slide_SPDT_Angled_CK_OS102011MA1Q; LCSC C136722; not fitted
SW8: SW_Push; SW_Push_1P1T_XKB_TS-1187A; LCSC C318884
U1: Ai-Thinker RA-08H; RA-08H; LCSC C2991932
U2: STM32G030K6Tx; LQFP-32_7x7mm_P0.8mm; LCSC C529331
U5: AP2112K-3.3; SOT-23-5; LCSC C51118

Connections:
+3.3V: C3.1, C4.1, C5.1, C6.1, C27.1, U1.9 (VCC), U2.4 (VDD), U5.5 (VOUT)
/2.4GHz: C18.1, R6.2
/915MHz: AE1.1, C18.2
/BOOT0: R19.1, U2.17 (PB2)
/MCU_DEBG_TX: J2.5, U2.9 (PA2)
/MCU_RST: C8.1, J2.2, SW8.2, U2.6 (NRST)
/MCU_UART_RX: J4.5, U1.11 (TXD/IO17), U2.23 (PA10/PA12)
/MCU_UART_TX: U1.10 (LPRXD/IO60), U2.22 (PA9/PA11)
/RADIO_RST: U1.16 (RST), U2.8 (PA1)
/SWDCLK: J2.4, U2.25 (PA14)
/SWDIO: J2.3, U2.24 (PA13)
/nBUZZ_BTN: SW5.2, U2.15 (PB0)
/nPAUSE_BTN: SW2.2, U2.12 (PA5)
/nRESET_BTN: SW3.2, SW6.2, U2.13 (PA6)
/nSTART_BTN: SW1.2, U2.16 (PB1)
/nTSEL_BTN: SW4.2, U2.14 (PA7)
GND: C3.2, C4.2, C5.2, C6.2, C8.2, C16.2, C17.2, C24.2, C27.2, J2.6, J4.6, J5.1, J5.2, J5.3, J13.2, R19.2, R20.2, SW1.1, SW2.1, SW3.1, SW4.1, SW5.1, SW6.1, SW8.1, U1.1 (GND), U1.17 (GND), U2.5 (VSS), U5.2 (GND); also elsewhere on the board
unnamed: C16.1, C17.1, R5.2, R6.1
unnamed: J3.1, J3.2, J3.3, SW7.2 (B)
unnamed: J4.4, U1.12 (RXD/IO16)
unnamed 20: J4.3, R20.1, U1.15 (IO2/BOOT); also elsewhere on the board
unnamed: R5.1, U1.18 (ANT)
VBAT: C24.1, J2.1, J4.1, J13.1, SW7.1 (A), U5.1 (VIN), U5.3 (EN)

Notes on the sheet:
1. Power button press sends LDO enable pulse, powers up 3.3V rail 2. MCU boots up, and sets nPWR_EN to latch device on 3. Automatic shutoff of system when charger is applied
STM32 Programmer
Radio Programmer
https://www.ti.com/lit/an/swra730/swra730.pdf
Judge Remote Buttons / Driver Ready Button
MCU
Radio
TI Reference Antenna & BOM
Mounting Holes
3.3V LDO
Radio: RA-08H

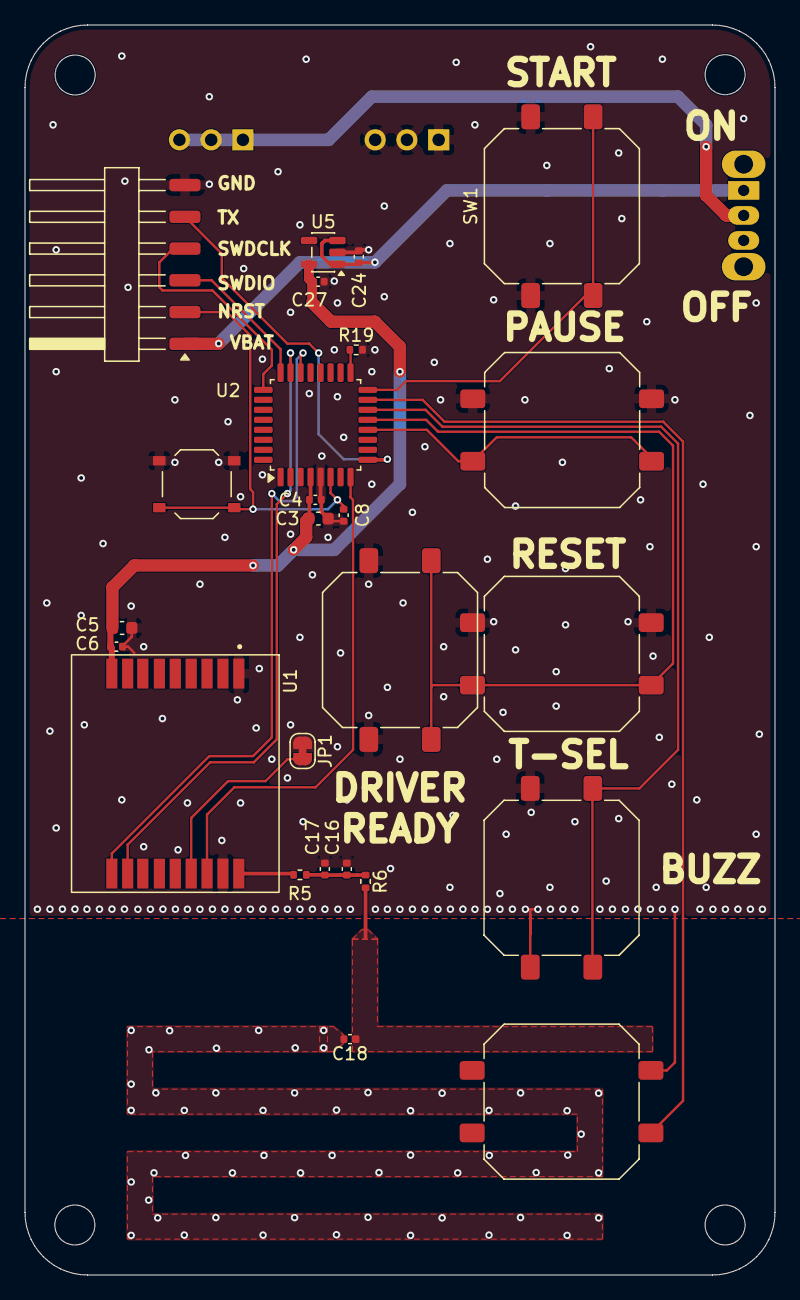
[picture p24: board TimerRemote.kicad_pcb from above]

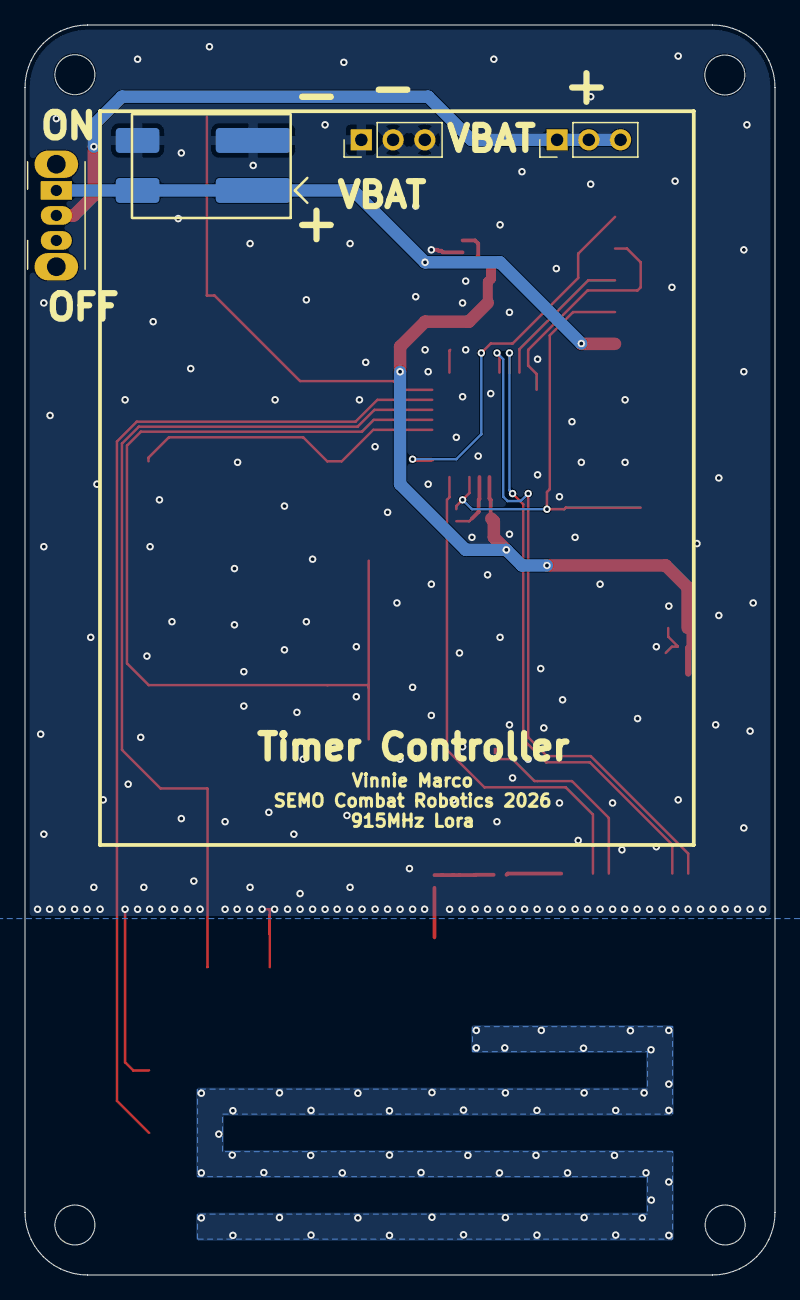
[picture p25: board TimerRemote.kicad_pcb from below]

Board: 2 copper layers, 60.0 x 100.0 mm, 33 parts (4 on the bottom side), 21 nets.

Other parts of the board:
JP1: Jumper_2_Bridged; SolderJumper-2_P1.3mm_Bridged_RoundedPad1.0x1.5mm

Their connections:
GND: JP1.1 (A); also elsewhere on the board
unnamed 20: JP1.2 (B); also elsewhere on the board

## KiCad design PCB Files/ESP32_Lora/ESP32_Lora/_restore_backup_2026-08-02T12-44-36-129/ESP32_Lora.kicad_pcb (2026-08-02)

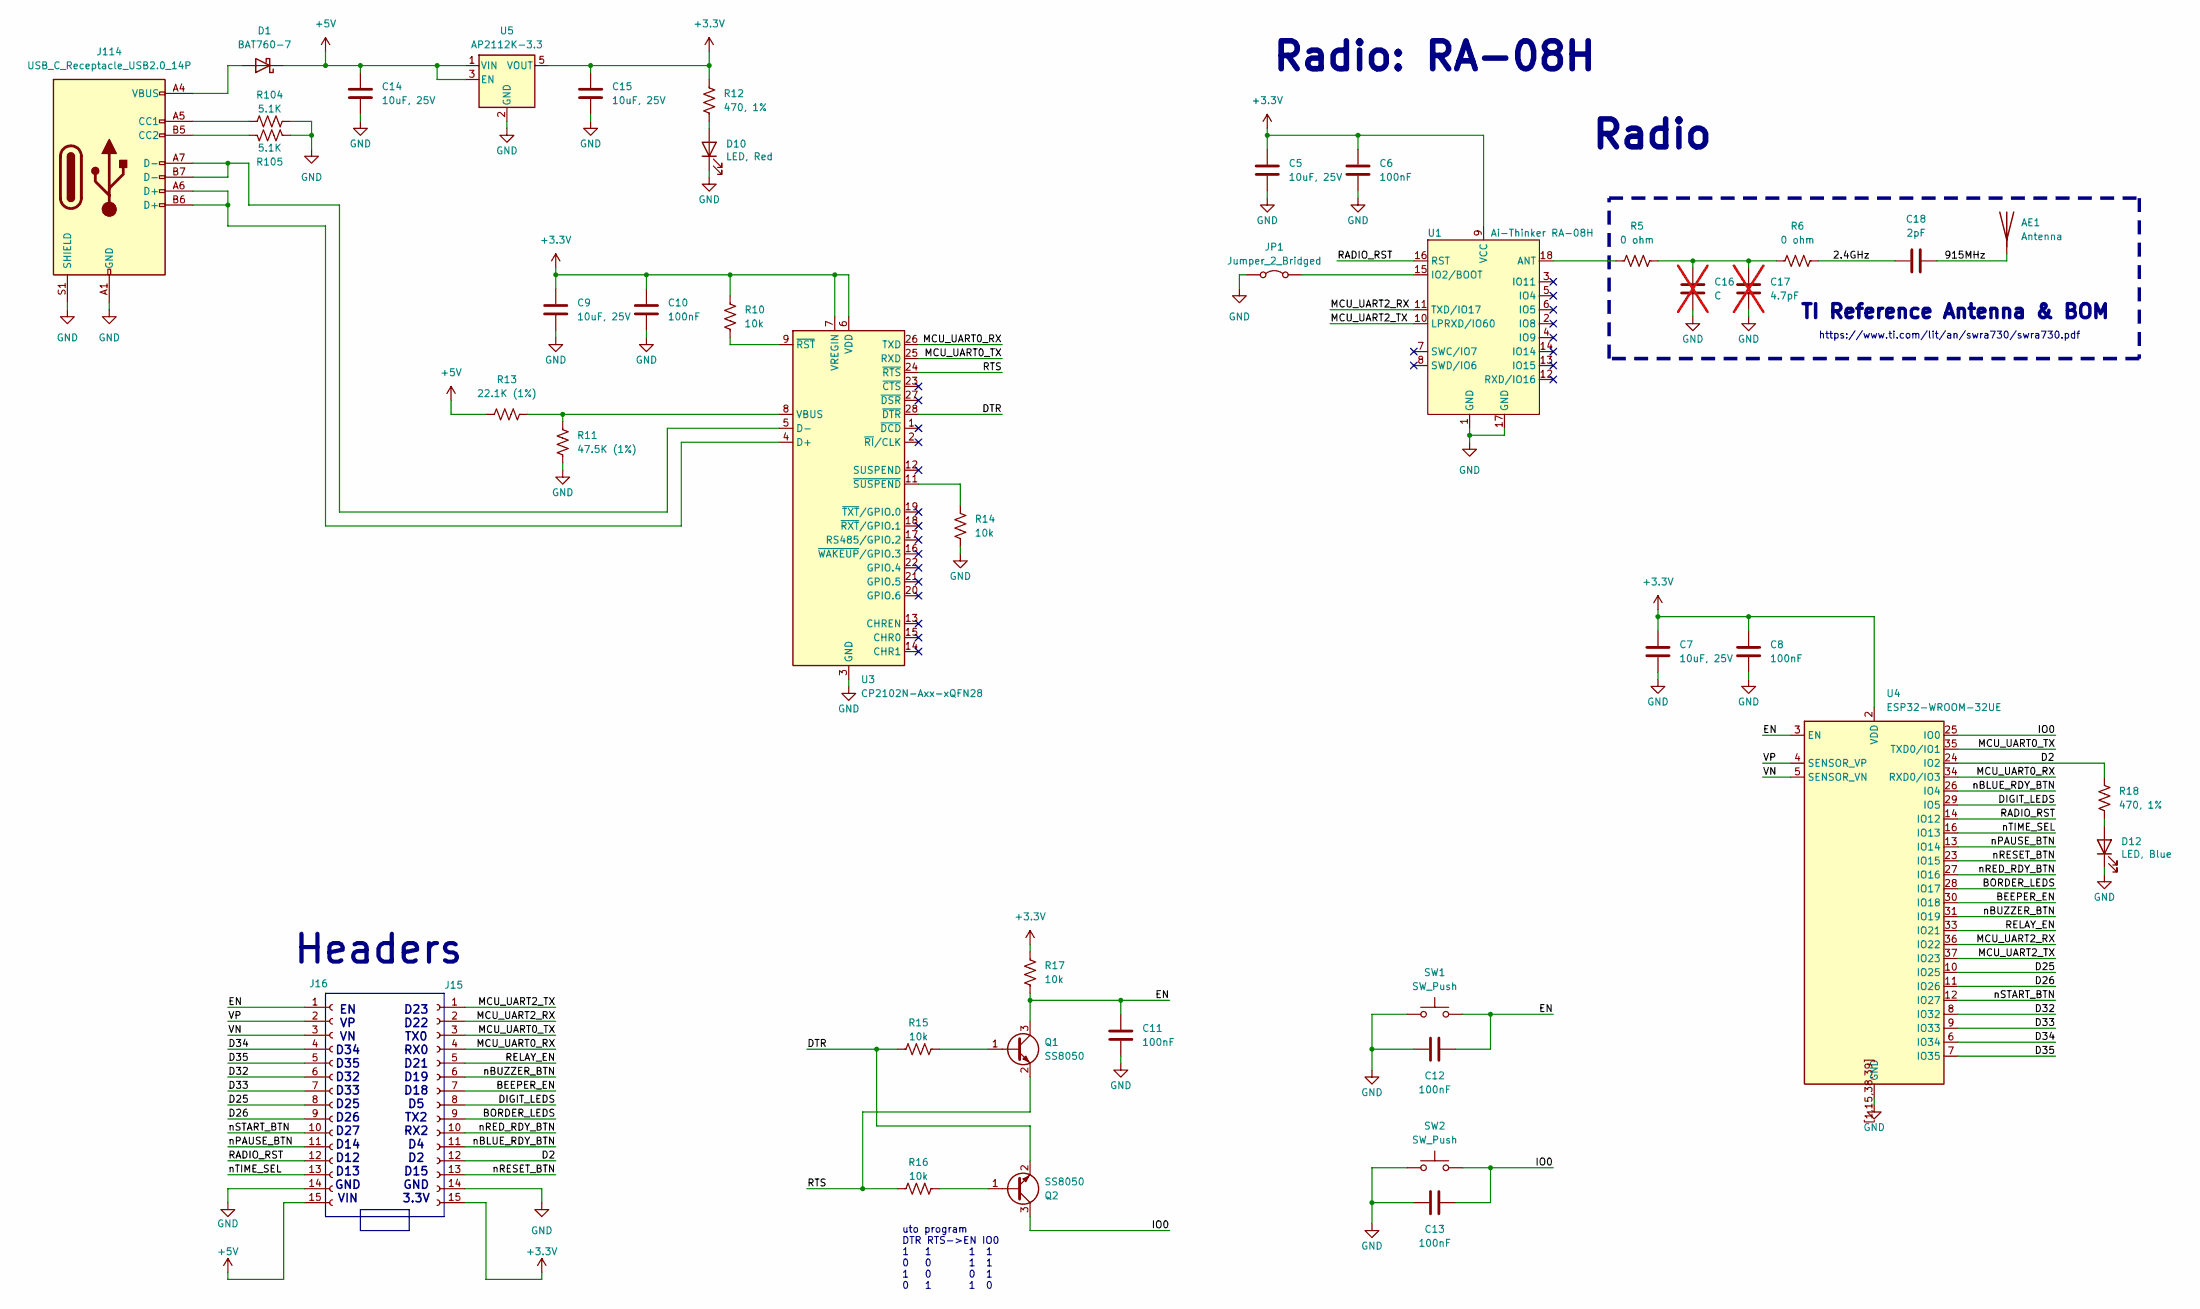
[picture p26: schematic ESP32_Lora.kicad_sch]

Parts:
AE1: Antenna
C5, C7, C9, C14, C15: 10uF, 25V; C_0603_1608Metric; LCSC C96446
C6, C8, C10, C11, C12, C13: 100nF; C_0402_1005Metric; LCSC C1525
C16: C; C_0402_1005Metric; LCSC DNU; not fitted
C17: 4.7pF; C_0402_1005Metric; MPN GRM0335C1H4R3CA01; LCSC C1569; not fitted
C18: 2pF; C_0402_1005Metric; LCSC C1558
D1: BAT760-7; D_SOD-323; LCSC C124187
D10: LED, Red; LED_0603_1608Metric; LCSC C965799
D12: LED, Blue; LED_0603_1608Metric; LCSC C965807
J15, J16: Conn_01x15_Socket; PinSocket_1x15_P2.54mm_Vertical; LCSC C124408
J114: USB_C_Receptacle_USB2.0_14P; USB_C_Receptacle_GCT_USB4105-xx-A_16P_TopMnt_Horizontal; LCSC PN C309347
JP1: Jumper_2_Bridged; SolderJumper-2_P1.3mm_Bridged_RoundedPad1.0x1.5mm
Q1, Q2: SS8050; SOT-23; LCSC C2834467
R5, R6: 0 ohm; R_0402_1005Metric; LCSC C17168
R10, R14, R15, R16, R17: 10k; R_0402_1005Metric; LCSC C25744
R11: 47.5K (1%); R_0402_1005Metric; LCSC C25744
R12, R18: 470, 1%; R_0402_1005Metric; LCSC C25117
R13: 22.1K (1%); R_0402_1005Metric; LCSC C25744
R104, R105: 5.1K; R_0201_0603Metric; LCSC PN C25837
SW1, SW2: SW_Push; SW_Push_SPST_NO_Alps_SKRK; LCSC C115357
U1: Ai-Thinker RA-08H; RA-08H; LCSC C2991932
U3: CP2102N-Axx-xQFN28; QFN-28-1EP_5x5mm_P0.5mm_EP3.35x3.35mm; LCSC C964632
U4: ESP32-WROOM-32UE; LCSC C701344
U5: AP2112K-3.3; SOT-23-5; LCSC C51118

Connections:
+3.3V: C5.1, C6.1, C7.1, C8.1, C9.1, C10.1, C15.1, J15.15, R10.1, R12.1, R17.1, U1.9 (VCC), U3.6 (VDD), U3.7 (VREGIN), U4.2 (VDD), U5.5 (VOUT)
+5V: C14.1, D1.1 (K), J16.15, R13.1, U5.1 (VIN), U5.3 (EN)
/2.4GHz: C18.1, R6.2
/915MHz: AE1.1, C18.2
/BEEPER_EN: J15.7, U4.30 (IO18)
/BORDER_LEDS: J15.9, U4.28 (IO17)
/D2: J15.12, R18.1, U4.24 (IO2)
/D25: J16.8, U4.10 (IO25)
/D26: J16.9, U4.11 (IO26)
/D32: J16.6, U4.8 (IO32)
/D33: J16.7, U4.9 (IO33)
/D34: J16.4, U4.6 (IO34)
/D35: J16.5, U4.7 (IO35)
/DIGIT_LEDS: J15.8, U4.29 (IO5)
/DTR: Q2.2 (E), R15.1, U3.28 (~DTR)
/EN: C11.1, C12.2, J16.1, Q1.3 (C), R17.2, SW1.2, U4.3 (EN)
/IO0: C13.2, Q2.3 (C), SW2.2, U4.25 (IO0)
/MCU_UART0_RX: J15.4, U3.26 (TXD), U4.34 (RXD0/IO3)
/MCU_UART0_TX: J15.3, U3.25 (RXD), U4.35 (TXD0/IO1)
/MCU_UART2_RX: J15.2, U1.11 (TXD/IO17), U4.36 (IO22)
/MCU_UART2_TX: J15.1, U1.10 (LPRXD/IO60), U4.37 (IO23)
/RADIO_RST: J16.12, U1.16 (RST), U4.14 (IO12)
/RELAY_EN: J15.5, U4.33 (IO21)
/RTS: Q1.2 (E), R16.1, U3.24 (~RTS)
/VN: J16.3, U4.5 (SENSOR_VN)
/VP: J16.2, U4.4 (SENSOR_VP)
/nBLUE_RDY_BTN: J15.11, U4.26 (IO4)
/nBUZZER_BTN: J15.6, U4.31 (IO19)
/nPAUSE_BTN: J16.11, U4.13 (IO14)
/nRED_RDY_BTN: J15.10, U4.27 (IO16)
/nRESET_BTN: J15.13, U4.23 (IO15)
/nSTART_BTN: J16.10, U4.12 (IO27)
/nTIME_SEL: J16.13, U4.16 (IO13)
GND: C5.2, C6.2, C7.2, C8.2, C9.2, C10.2, C11.2, C12.1, C13.1, C14.2, C15.2, C16.2, C17.2, D10.1 (K), D12.1 (K), J15.14, J16.14, J114.A1 (GND), J114.A12 (GND), J114.B1 (GND), J114.B12 (GND), J114.S1 (SHIELD), JP1.1 (A), R11.2, R14.2, R104.2, R105.2, SW1.1, SW2.1, U1.1 (GND), U1.17 (GND), U3.3 (GND), U3.29 (GND), U4.1 (GND), U4.15 (GND), U4.38 (GND), U4.39 (GND), U4.[1,15,38,39] (GND), U5.2 (GND)
unnamed: C16.1, C17.1, R5.2, R6.1
unnamed: D1.2 (A), J114.A4 (VBUS), J114.A9 (VBUS), J114.B4 (VBUS), J114.B9 (VBUS)
unnamed: D10.2 (A), R12.2
unnamed: D12.2 (A), R18.2
unnamed: J114.A5 (CC1), R104.1
unnamed: J114.B5 (CC2), R105.1
unnamed: JP1.2 (B), U1.15 (IO2/BOOT)
unnamed: Q1.1 (B), R15.2
unnamed: Q2.1 (B), R16.2
unnamed: R5.1, U1.18 (ANT)
unnamed: J114.A6 (D+), J114.B6 (D+), U3.4 (D+)
unnamed: J114.A7 (D-), J114.B7 (D-), U3.5 (D-)
unnamed: R11.1, R13.2, U3.8 (VBUS)
unnamed: R10.2, U3.9 (~RST)
unnamed: R14.1, U3.11 (~SUSPEND)

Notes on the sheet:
TI Reference Antenna & BOM
EN VP VN D34 D35 D32 D33 D25 D26 D27 D14 D12 D13 GND VIN
Headers
Radio: RA-08H
uto program DTR RTS->EN IO0 1 1 1 1 0 0 1 1 1 0 0 1 0 1 1 0
https://www.ti.com/lit/an/swra730/swra730.pdf
Radio
D23 D22 TX0 RX0 D21 D19 D18 D5 TX2 RX2 D4 D2 D15 GND 3.3V

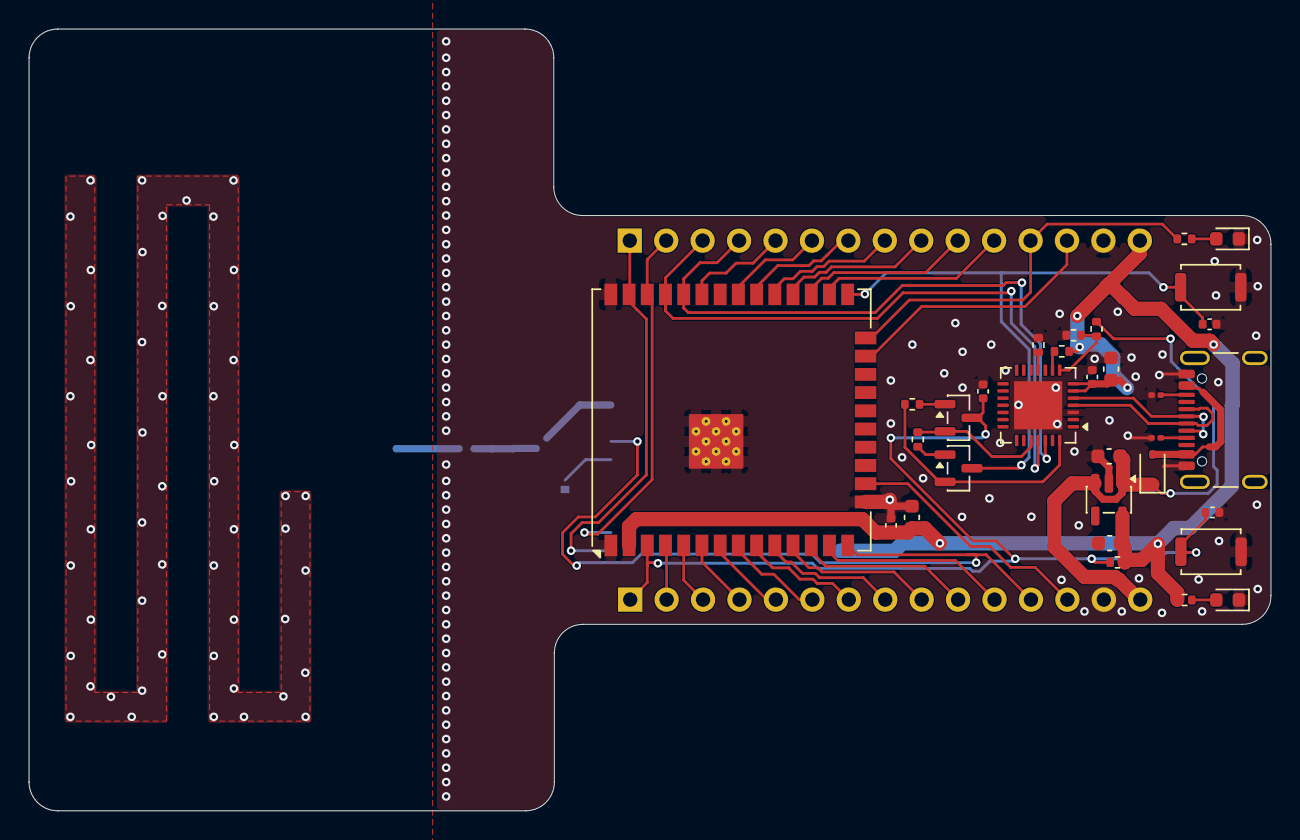
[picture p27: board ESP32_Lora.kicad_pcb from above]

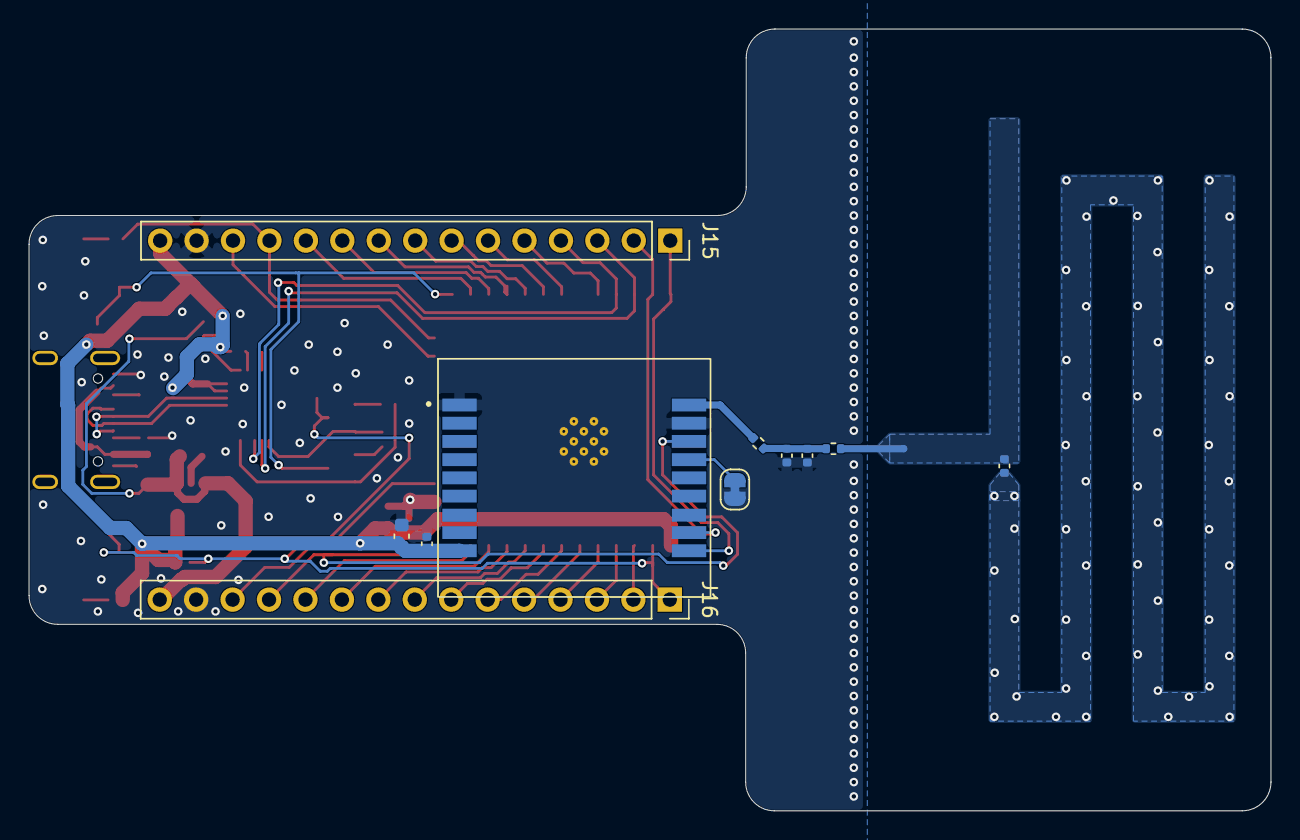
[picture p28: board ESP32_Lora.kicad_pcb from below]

Board: 2 copper layers, 86.6 x 54.5 mm, 42 parts (11 on the bottom side), 48 nets.

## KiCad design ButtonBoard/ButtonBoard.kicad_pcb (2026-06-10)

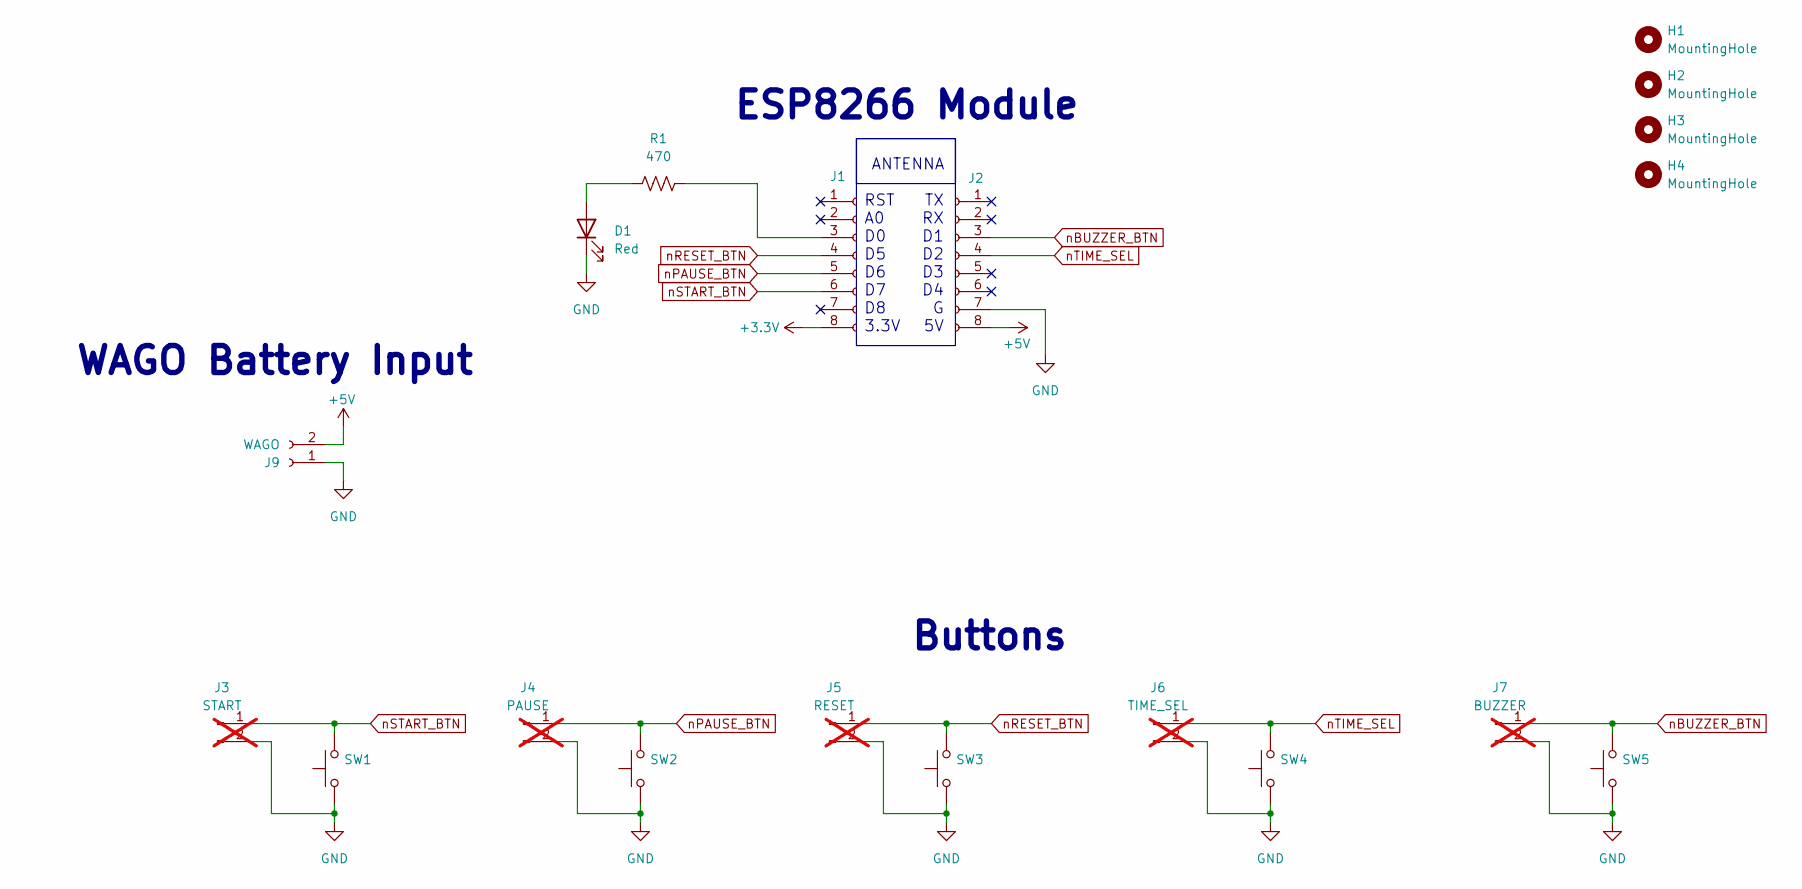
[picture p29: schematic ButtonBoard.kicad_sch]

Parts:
D1: Red; LED_0603_1608Metric; LCSC C2286
H1, H2, H3, H4: MountingHole; MountingHole_3.2mm_M3
J1, J2: Conn_01x08_Socket; PinSocket_1x08_P2.54mm_Vertical; LCSC C42431840
J3: START; PinHeader_1x02_P2.54mm_Vertical; not fitted
J4: PAUSE; PinHeader_1x02_P2.54mm_Vertical; not fitted
J5: RESET; PinHeader_1x02_P2.54mm_Vertical; not fitted
J6: TIME_SEL; PinHeader_1x02_P2.54mm_Vertical; not fitted
J7: BUZZER; PinHeader_1x02_P2.54mm_Vertical; not fitted
J9: WAGO; 2060-452_998-404; LCSC C2765055
R1: 470; R_0603_1608Metric; LCSC C23179
SW1: START; SW_PUSH-12mm; LCSC C2888699
SW2: PAUSE; SW_PUSH-12mm; LCSC C2888699
SW3: RESET; SW_PUSH-12mm; LCSC C2888699
SW4: TIME_SEL; SW_PUSH-12mm; LCSC C2888699
SW5: BUZZER; SW_PUSH-12mm; LCSC C2888699

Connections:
+3.3V: J1.8
+5V: J2.8, J9.2
GND: D1.1 (K), J2.7, J3.2, J4.2, J5.2, J6.2, J7.2, J9.1, SW1.1, SW2.1, SW3.1, SW4.1, SW5.1
unnamed: D1.2 (A), R1.1
unnamed: J1.3, R1.2
nBUZZER_BTN: J2.3, J7.1, SW5.2
nPAUSE_BTN: J1.5, J4.1, SW2.2
nRESET_BTN: J1.4, J5.1, SW3.2
nSTART_BTN: J1.6, J3.1, SW1.2
nTIME_SEL: J2.4, J6.1, SW4.2

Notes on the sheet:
ESP8266 Module
Buttons
RST A0 D0 D5 D6 D7 D8 3.3V
WAGO Battery Input
ANTENNA
TX RX D1 D2 D3 D4 G 5V

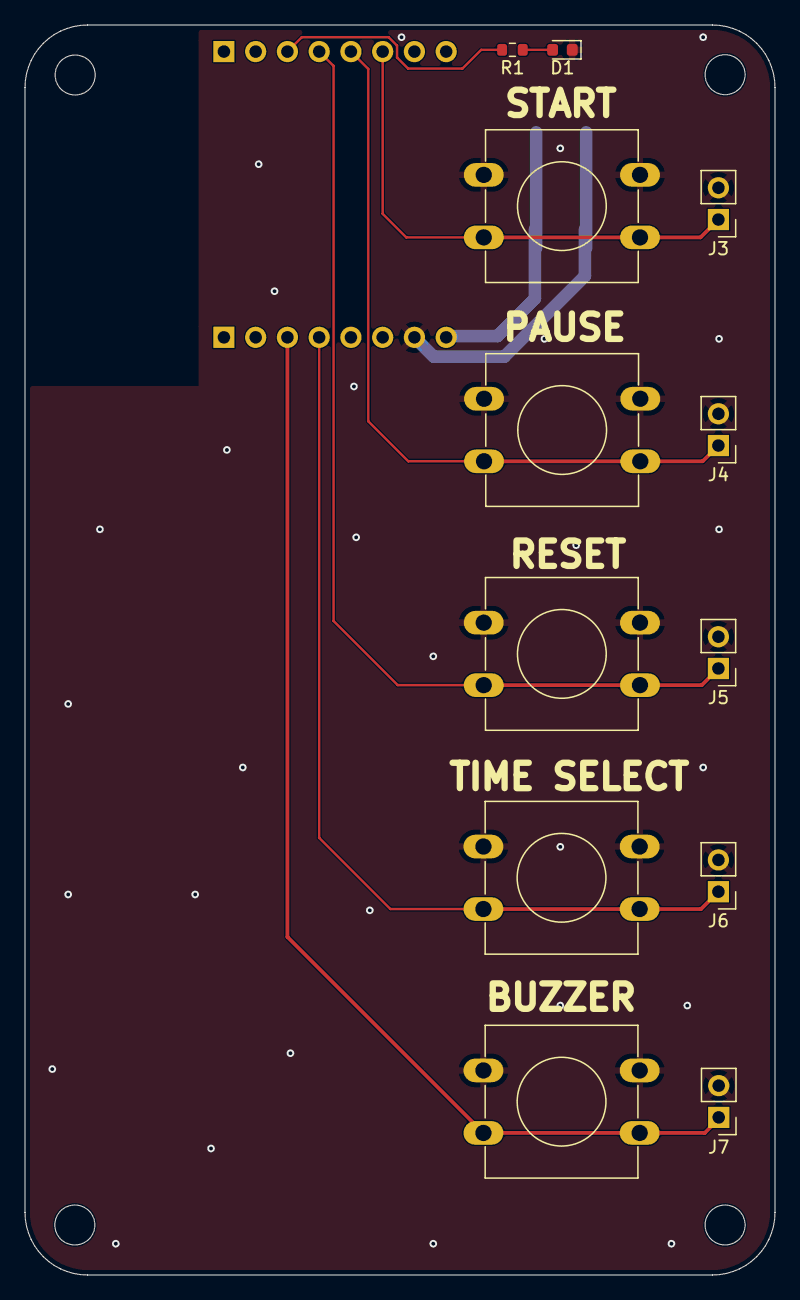
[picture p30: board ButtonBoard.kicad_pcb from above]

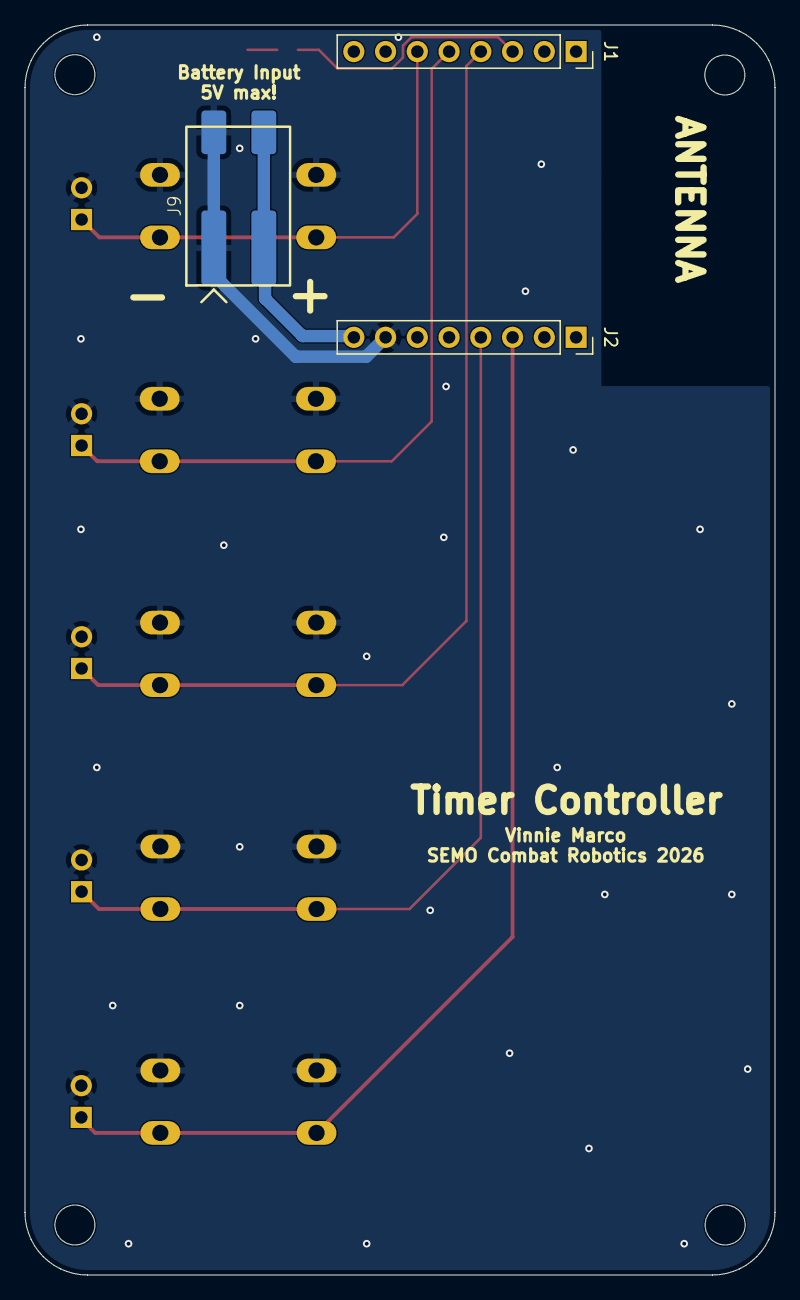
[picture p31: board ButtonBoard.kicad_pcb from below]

Board: 2 copper layers, 60.0 x 100.0 mm, 19 parts (3 on the bottom side), 9 nets.

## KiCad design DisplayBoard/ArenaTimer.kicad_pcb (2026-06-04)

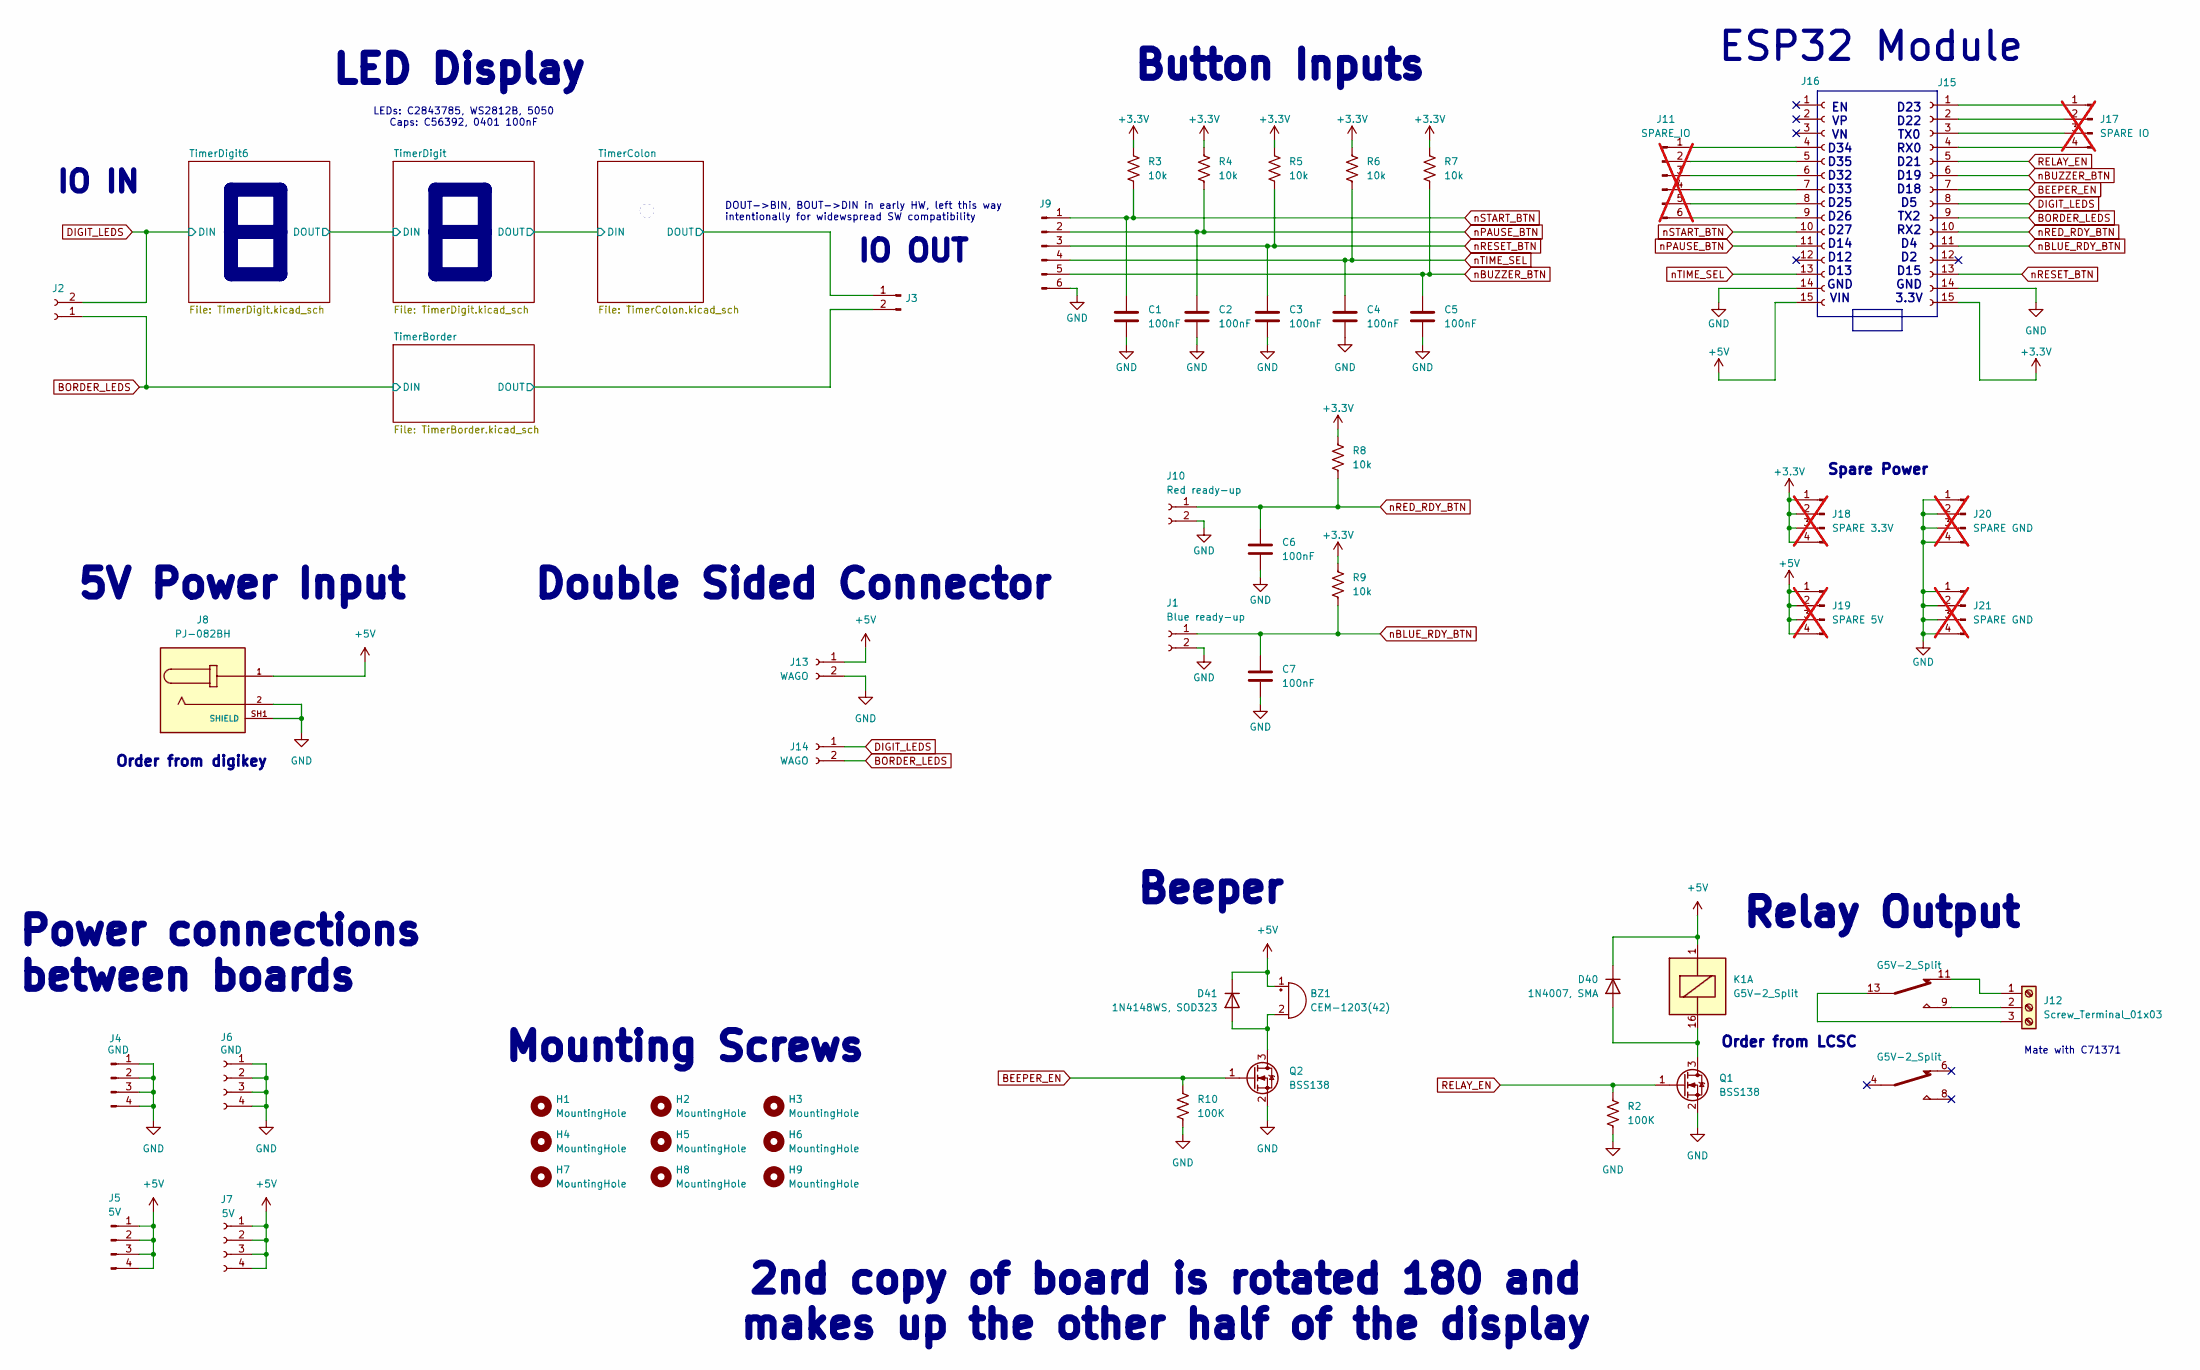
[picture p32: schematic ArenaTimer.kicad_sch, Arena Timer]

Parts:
BZ1: CEM-1203(42); Buzzer_TDK_PS1240P02BT_D12.2mm_H6.5mm; LCSC C3812098
C1, C2, C3, C4, C5, C6, C7: 100nF; C_0402_1005Metric; LCSC C1581
D40: 1N4007, SMA; D_SMA; LCSC C727081
D41: 1N4148WS, SOD323; D_SOD-323; LCSC C2128
H1, H2, H3, H4, H5, H6, H7, H8, H9: MountingHole; MountingHole_3.2mm_M3
J1: Blue ready-up; JST_EH_S2B-EH_1x02_P2.50mm_Horizontal; LCSC C19271377
J2: Conn_01x02_Socket; PinSocket_1x02_P2.54mm_Horizontal; LCSC C2897384
J3: Conn_01x02_Pin; PinHeader_1x02_P2.54mm_Horizontal; LCSC C492410
J4: GND; PinHeader_1x04_P2.54mm_Horizontal; LCSC C492412
J5: 5V; PinHeader_1x04_P2.54mm_Horizontal; LCSC C492412
J6: GND; PinSocket_1x04_P2.54mm_Horizontal; LCSC C2897386
J7: 5V; PinSocket_1x04_P2.54mm_Horizontal; LCSC C2897386
J8: PJ-082BH; SAMESKY_PJ-082BH; PARTREV 1.06; LCSC C3094233
J9: Conn_01x06_Pin; JST_EH_S6B-EH_1x06_P2.50mm_Horizontal; LCSC C157919
J10: Red ready-up; JST_EH_S2B-EH_1x02_P2.50mm_Horizontal; LCSC C19271377
J11: SPARE_IO; PinHeader_1x06_P2.54mm_Vertical; not fitted
J12: Screw_Terminal_01x03; TerminalBlock_MaiXu_MX126-5.0-03P_1x03_P5.00mm; LCSC C8377
J13, J14: WAGO; 2060-452_998-404; LCSC C2765055
J15, J16: Conn_01x15_Socket; PinSocket_1x15_P2.54mm_Vertical; LCSC C124408
J17: SPARE IO; PinHeader_1x04_P2.54mm_Vertical; not fitted
J18: SPARE 3.3V; PinHeader_1x04_P2.54mm_Vertical; not fitted
J19: SPARE 5V; PinHeader_1x04_P2.54mm_Vertical; not fitted
J20, J21: SPARE GND; PinHeader_1x04_P2.54mm_Vertical; not fitted
K1: G5V-2_Split; Relay_DPDT_Omron_G5V-2; LCSC C27269
Q1, Q2: BSS138; SOT-323_SC-70; LCSC C5224279
R2, R10: 100K; R_0402_1005Metric; LCSC C25530
R3, R4, R5, R6, R7, R8, R9: 10k; R_0402_1005Metric; LCSC C25744

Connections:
+3.3V: J15.15, J18.1, J18.2, J18.3, J18.4, R3.1, R4.1, R5.1, R6.1, R7.1, R8.1, R9.1
+5V: BZ1.1 (+), D40.1 (K), D41.1 (K), J5.1, J5.2, J5.3, J5.4, J7.1, J7.2, J7.3, J7.4, J8.1, J13.1, J16.15, J19.1, J19.2, J19.3, J19.4, K1.1; also elsewhere on the board
/TimerBorder/DOUT: J3.2; also elsewhere on the board
/TimerColon/DOUT: J3.1; also elsewhere on the board
BEEPER_EN: J15.7, Q2.1 (G), R10.1
BORDER_LEDS: J2.1, J14.2, J15.9; also elsewhere on the board
DIGIT_LEDS: J2.2, J14.1, J15.8; also elsewhere on the board
GND: C1.2, C2.2, C3.2, C4.2, C5.2, C6.2, C7.2, J1.2, J4.1, J4.2, J4.3, J4.4, J6.1, J6.2, J6.3, J6.4, J8.2, J8.SH1 (SHIELD), J8.SH2 (SHIELD), J8.SH3 (SHIELD), J8.SH4 (SHIELD), J9.6, J10.2, J13.2, J15.14, J16.14, J20.1, J20.2, J20.3, J20.4, J21.1, J21.2, J21.3, J21.4, Q1.2 (S), Q2.2 (S), R2.2, R10.2; also elsewhere on the board
unnamed: BZ1.2 (-), D41.2 (A), Q2.3 (D)
unnamed: D40.2 (A), K1.16, Q1.3 (D)
unnamed: J11.1, J16.4
unnamed: J11.2, J16.5
unnamed: J11.3, J16.6
unnamed: J11.4, J16.7
unnamed: J11.5, J16.8
unnamed: J11.6, J16.9
unnamed: J12.1, K1.11
unnamed: J12.2, K1.9
unnamed: J12.3, K1.13
unnamed: J15.1, J17.1
unnamed: J15.2, J17.2
unnamed: J15.3, J17.3
unnamed: J15.4, J17.4
RELAY_EN: J15.5, Q1.1 (G), R2.1
nBLUE_RDY_BTN: C7.1, J1.1, J15.11, R9.2
nBUZZER_BTN: C5.1, J9.5, J15.6, R7.2
nPAUSE_BTN: C2.1, J9.2, J16.11, R4.2
nRED_RDY_BTN: C6.1, J10.1, J15.10, R8.2
nRESET_BTN: C3.1, J9.3, J15.13, R5.2
nSTART_BTN: C1.1, J9.1, J16.10, R3.2
nTIME_SEL: C4.1, J9.4, J16.13, R6.2

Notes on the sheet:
Spare Power
EN VP VN D34 D35 D32 D33 D25 D26 D27 D14 D12 D13 GND VIN
Order from digikey
Mate with C71371
IO IN
Beeper
Power connections between boards
5V Power Input
Order from LCSC
IO OUT
Double Sided Connector
2nd copy of board is rotated 180 and makes up the other half of the display
Relay Output
Button Inputs
Mounting Screws
D23 D22 TX0 RX0 D21 D19 D18 D5 TX2 RX2 D4 D2 D15 GND 3.3V
LEDs: C2843785, WS2812B, 5050 Caps: C56392, 0401 100nF
ESP32 Module
DOUT->BIN, BOUT->DIN in early HW, left this way intentionally for widewspread SW compatibility
LED Display

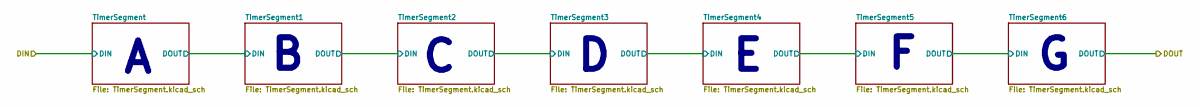
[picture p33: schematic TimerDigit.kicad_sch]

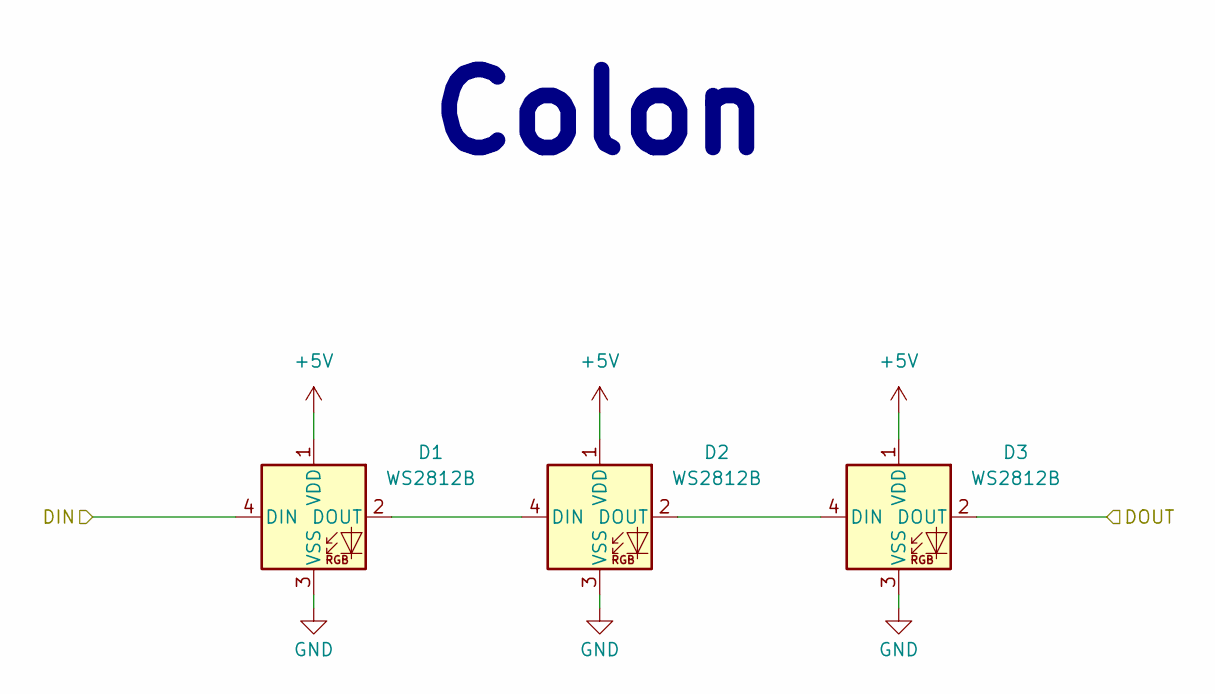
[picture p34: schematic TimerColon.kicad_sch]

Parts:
D1, D2, D3: WS2812B; LED_WS2812B_PLCC4_5.0x5.0mm_P3.2mm; LCSC C2843785

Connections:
+5V: D1.1 (VDD), D2.1 (VDD), D3.1 (VDD); also elsewhere on the board
/TimerColon/DIN: D1.4 (DIN); also elsewhere on the board
/TimerColon/DOUT: D3.2 (DOUT); also elsewhere on the board
GND: D1.3 (VSS), D2.3 (VSS), D3.3 (VSS); also elsewhere on the board
unnamed: D1.2 (DOUT), D2.4 (DIN)
unnamed: D2.2 (DOUT), D3.4 (DIN)

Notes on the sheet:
Colon


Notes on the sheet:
Front Side


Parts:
D70, D71, D72, D73, D74, D75, D76: WS2812B; LED_WS2812B_PLCC4_5.0x5.0mm_P3.2mm; LCSC C2843785

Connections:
+5V: D70.1 (VDD), D71.1 (VDD), D72.1 (VDD), D73.1 (VDD), D74.1 (VDD), D75.1 (VDD), D76.1 (VDD); also elsewhere on the board
/TimerDigit/DIN: D70.4 (DIN); also elsewhere on the board
/TimerDigit/TimerSegment/DOUT: D76.2 (DOUT); also elsewhere on the board
GND: D70.3 (VSS), D71.3 (VSS), D72.3 (VSS), D73.3 (VSS), D74.3 (VSS), D75.3 (VSS), D76.3 (VSS); also elsewhere on the board
unnamed: D70.2 (DOUT), D71.4 (DIN)
unnamed: D71.2 (DOUT), D72.4 (DIN)
unnamed: D72.2 (DOUT), D73.4 (DIN)
unnamed: D73.2 (DOUT), D74.4 (DIN)
unnamed: D74.2 (DOUT), D75.4 (DIN)
unnamed: D75.2 (DOUT), D76.4 (DIN)

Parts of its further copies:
D77, D78, D79, D80, D81, D82, D83, D112, D113, D114, D115, D116, D117, D118, D154, D155, D156, D157, D158, D159, D160, D238, D239, D240, D241, D242, D243, D244, D245, D246, D247, D248, D249, D250, D251, D287, D288, D289, D290, D291, D292, D293, D294, D295, D296, D297, D298, D299, D300, D301, D302, D303, D304, D305, D306, D307, D308, D309, D310, D311, D312, D313, D314, D315, D316, D317, D318, D319, D320, D321, D322, D323, D324, D325, D326, D327, D328, D329, D330, D331, D332, D333, D334, D335, D336, D337, D338, D339, D340, D341, D342: WS2812B; LED_WS2812B_PLCC4_5.0x5.0mm_P3.2mm; LCSC C2843785

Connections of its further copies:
+5V: D77.1 (VDD), D78.1 (VDD), D79.1 (VDD), D80.1 (VDD), D81.1 (VDD), D82.1 (VDD), D83.1 (VDD), D112.1 (VDD), D113.1 (VDD), D114.1 (VDD), D115.1 (VDD), D116.1 (VDD), D117.1 (VDD), D118.1 (VDD), D154.1 (VDD), D155.1 (VDD), D156.1 (VDD), D157.1 (VDD), D158.1 (VDD), D159.1 (VDD), D160.1 (VDD), D238.1 (VDD), D239.1 (VDD), D240.1 (VDD), D241.1 (VDD), D242.1 (VDD), D243.1 (VDD), D244.1 (VDD), D245.1 (VDD), D246.1 (VDD), D247.1 (VDD), D248.1 (VDD), D249.1 (VDD), D250.1 (VDD), D251.1 (VDD), D287.1 (VDD), D288.1 (VDD), D289.1 (VDD), D290.1 (VDD), D291.1 (VDD), D292.1 (VDD), D293.1 (VDD), D294.1 (VDD), D295.1 (VDD), D296.1 (VDD), D297.1 (VDD), D298.1 (VDD), D299.1 (VDD), D300.1 (VDD), D301.1 (VDD), D302.1 (VDD), D303.1 (VDD), D304.1 (VDD), D305.1 (VDD), D306.1 (VDD), D307.1 (VDD), D308.1 (VDD), D309.1 (VDD), D310.1 (VDD), D311.1 (VDD), D312.1 (VDD), D313.1 (VDD), D314.1 (VDD), D315.1 (VDD), D316.1 (VDD), D317.1 (VDD), D318.1 (VDD), D319.1 (VDD), D320.1 (VDD), D321.1 (VDD), D322.1 (VDD), D323.1 (VDD), D324.1 (VDD), D325.1 (VDD), D326.1 (VDD), D327.1 (VDD), D328.1 (VDD), D329.1 (VDD), D330.1 (VDD), D331.1 (VDD), D332.1 (VDD), D333.1 (VDD), D334.1 (VDD), D335.1 (VDD), D336.1 (VDD), D337.1 (VDD), D338.1 (VDD), D339.1 (VDD), D340.1 (VDD), D341.1 (VDD), D342.1 (VDD); also elsewhere on the board
/TimerColon/DIN: D293.2 (DOUT); also elsewhere on the board
/TimerDigit6/TimerSegment1/DOUT: D308.4 (DIN), D342.2 (DOUT)
/TimerDigit6/TimerSegment2/DOUT: D301.4 (DIN), D314.2 (DOUT)
/TimerDigit6/TimerSegment3/DOUT: D294.4 (DIN), D307.2 (DOUT)
/TimerDigit6/TimerSegment4/DOUT: D300.2 (DOUT), D322.4 (DIN)
/TimerDigit6/TimerSegment5/DOUT: D315.4 (DIN), D328.2 (DOUT)
/TimerDigit6/TimerSegment/DOUT: D335.2 (DOUT), D336.4 (DIN)
/TimerDigit/DIN: D321.2 (DOUT); also elsewhere on the board
/TimerDigit/TimerSegment1/DOUT: D83.2 (DOUT), D112.4 (DIN)
/TimerDigit/TimerSegment2/DOUT: D118.2 (DOUT), D154.4 (DIN)
/TimerDigit/TimerSegment3/DOUT: D160.2 (DOUT), D238.4 (DIN)
/TimerDigit/TimerSegment4/DOUT: D244.2 (DOUT), D245.4 (DIN)
/TimerDigit/TimerSegment5/DOUT: D251.2 (DOUT), D287.4 (DIN)
/TimerDigit/TimerSegment/DOUT: D77.4 (DIN); also elsewhere on the board
DIGIT_LEDS: D329.4 (DIN); also elsewhere on the board
GND: D77.3 (VSS), D78.3 (VSS), D79.3 (VSS), D80.3 (VSS), D81.3 (VSS), D82.3 (VSS), D83.3 (VSS), D112.3 (VSS), D113.3 (VSS), D114.3 (VSS), D115.3 (VSS), D116.3 (VSS), D117.3 (VSS), D118.3 (VSS), D154.3 (VSS), D155.3 (VSS), D156.3 (VSS), D157.3 (VSS), D158.3 (VSS), D159.3 (VSS), D160.3 (VSS), D238.3 (VSS), D239.3 (VSS), D240.3 (VSS), D241.3 (VSS), D242.3 (VSS), D243.3 (VSS), D244.3 (VSS), D245.3 (VSS), D246.3 (VSS), D247.3 (VSS), D248.3 (VSS), D249.3 (VSS), D250.3 (VSS), D251.3 (VSS), D287.3 (VSS), D288.3 (VSS), D289.3 (VSS), D290.3 (VSS), D291.3 (VSS), D292.3 (VSS), D293.3 (VSS), D294.3 (VSS), D295.3 (VSS), D296.3 (VSS), D297.3 (VSS), D298.3 (VSS), D299.3 (VSS), D300.3 (VSS), D301.3 (VSS), D302.3 (VSS), D303.3 (VSS), D304.3 (VSS), D305.3 (VSS), D306.3 (VSS), D307.3 (VSS), D308.3 (VSS), D309.3 (VSS), D310.3 (VSS), D311.3 (VSS), D312.3 (VSS), D313.3 (VSS), D314.3 (VSS), D315.3 (VSS), D316.3 (VSS), D317.3 (VSS), D318.3 (VSS), D319.3 (VSS), D320.3 (VSS), D321.3 (VSS), D322.3 (VSS), D323.3 (VSS), D324.3 (VSS), D325.3 (VSS), D326.3 (VSS), D327.3 (VSS), D328.3 (VSS), D329.3 (VSS), D330.3 (VSS), D331.3 (VSS), D332.3 (VSS), D333.3 (VSS), D334.3 (VSS), D335.3 (VSS), D336.3 (VSS), D337.3 (VSS), D338.3 (VSS), D339.3 (VSS), D340.3 (VSS), D341.3 (VSS), D342.3 (VSS); also elsewhere on the board
unnamed: D77.2 (DOUT), D78.4 (DIN)
unnamed: D78.2 (DOUT), D79.4 (DIN)
unnamed: D79.2 (DOUT), D80.4 (DIN)
unnamed: D80.2 (DOUT), D81.4 (DIN)
unnamed: D81.2 (DOUT), D82.4 (DIN)
unnamed: D82.2 (DOUT), D83.4 (DIN)
unnamed: D112.2 (DOUT), D113.4 (DIN)
unnamed: D113.2 (DOUT), D114.4 (DIN)
unnamed: D114.2 (DOUT), D115.4 (DIN)
unnamed: D115.2 (DOUT), D116.4 (DIN)
unnamed: D116.2 (DOUT), D117.4 (DIN)
unnamed: D117.2 (DOUT), D118.4 (DIN)
unnamed: D154.2 (DOUT), D155.4 (DIN)
unnamed: D155.2 (DOUT), D156.4 (DIN)
unnamed: D156.2 (DOUT), D157.4 (DIN)
unnamed: D157.2 (DOUT), D158.4 (DIN)
unnamed: D158.2 (DOUT), D159.4 (DIN)
unnamed: D159.2 (DOUT), D160.4 (DIN)
unnamed: D238.2 (DOUT), D239.4 (DIN)
unnamed: D239.2 (DOUT), D240.4 (DIN)
unnamed: D240.2 (DOUT), D241.4 (DIN)
unnamed: D241.2 (DOUT), D242.4 (DIN)
unnamed: D242.2 (DOUT), D243.4 (DIN)
unnamed: D243.2 (DOUT), D244.4 (DIN)
unnamed: D245.2 (DOUT), D246.4 (DIN)
unnamed: D246.2 (DOUT), D247.4 (DIN)
unnamed: D247.2 (DOUT), D248.4 (DIN)
unnamed: D248.2 (DOUT), D249.4 (DIN)
unnamed: D249.2 (DOUT), D250.4 (DIN)
unnamed: D250.2 (DOUT), D251.4 (DIN)
unnamed: D287.2 (DOUT), D288.4 (DIN)
unnamed: D288.2 (DOUT), D289.4 (DIN)
unnamed: D289.2 (DOUT), D290.4 (DIN)
unnamed: D290.2 (DOUT), D291.4 (DIN)
unnamed: D291.2 (DOUT), D292.4 (DIN)
unnamed: D292.2 (DOUT), D293.4 (DIN)
unnamed: D294.2 (DOUT), D295.4 (DIN)
unnamed: D295.2 (DOUT), D296.4 (DIN)
unnamed: D296.2 (DOUT), D297.4 (DIN)
unnamed: D297.2 (DOUT), D298.4 (DIN)
unnamed: D298.2 (DOUT), D299.4 (DIN)
unnamed: D299.2 (DOUT), D300.4 (DIN)
unnamed: D301.2 (DOUT), D302.4 (DIN)
unnamed: D302.2 (DOUT), D303.4 (DIN)
unnamed: D303.2 (DOUT), D304.4 (DIN)
unnamed: D304.2 (DOUT), D305.4 (DIN)
unnamed: D305.2 (DOUT), D306.4 (DIN)
unnamed: D306.2 (DOUT), D307.4 (DIN)
unnamed: D308.2 (DOUT), D309.4 (DIN)
unnamed: D309.2 (DOUT), D310.4 (DIN)
unnamed: D310.2 (DOUT), D311.4 (DIN)
unnamed: D311.2 (DOUT), D312.4 (DIN)
unnamed: D312.2 (DOUT), D313.4 (DIN)
unnamed: D313.2 (DOUT), D314.4 (DIN)
unnamed: D315.2 (DOUT), D316.4 (DIN)
unnamed: D316.2 (DOUT), D317.4 (DIN)
unnamed: D317.2 (DOUT), D318.4 (DIN)
unnamed: D318.2 (DOUT), D319.4 (DIN)
unnamed: D319.2 (DOUT), D320.4 (DIN)
unnamed: D320.2 (DOUT), D321.4 (DIN)
unnamed: D322.2 (DOUT), D323.4 (DIN)
unnamed: D323.2 (DOUT), D324.4 (DIN)
unnamed: D324.2 (DOUT), D325.4 (DIN)
unnamed: D325.2 (DOUT), D326.4 (DIN)
unnamed: D326.2 (DOUT), D327.4 (DIN)
unnamed: D327.2 (DOUT), D328.4 (DIN)
unnamed: D329.2 (DOUT), D330.4 (DIN)
unnamed: D330.2 (DOUT), D331.4 (DIN)
unnamed: D331.2 (DOUT), D332.4 (DIN)
unnamed: D332.2 (DOUT), D333.4 (DIN)
unnamed: D333.2 (DOUT), D334.4 (DIN)
unnamed: D334.2 (DOUT), D335.4 (DIN)
unnamed: D336.2 (DOUT), D337.4 (DIN)
unnamed: D337.2 (DOUT), D338.4 (DIN)
unnamed: D338.2 (DOUT), D339.4 (DIN)
unnamed: D339.2 (DOUT), D340.4 (DIN)
unnamed: D340.2 (DOUT), D341.4 (DIN)
unnamed: D341.2 (DOUT), D342.4 (DIN)


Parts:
D4, D5, D6, D7, D8, D9, D10, D11, D12, D13, D14, D15, D16, D17, D18, D19, D20, D21, D22, D23, D24, D25, D26, D27, D28, D29, D30, D31, D32, D33, D34, D35, D36, D37, D38: WS2812B; LED_WS2812B_PLCC4_5.0x5.0mm_P3.2mm; LCSC C2843785

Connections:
+5V: D4.1 (VDD), D5.1 (VDD), D6.1 (VDD), D7.1 (VDD), D8.1 (VDD), D9.1 (VDD), D10.1 (VDD), D11.1 (VDD), D12.1 (VDD), D13.1 (VDD), D14.1 (VDD), D15.1 (VDD), D16.1 (VDD), D17.1 (VDD), D18.1 (VDD), D19.1 (VDD), D20.1 (VDD), D21.1 (VDD), D22.1 (VDD), D23.1 (VDD), D24.1 (VDD), D25.1 (VDD), D26.1 (VDD), D27.1 (VDD), D28.1 (VDD), D29.1 (VDD), D30.1 (VDD), D31.1 (VDD), D32.1 (VDD), D33.1 (VDD), D34.1 (VDD), D35.1 (VDD), D36.1 (VDD), D37.1 (VDD), D38.1 (VDD); also elsewhere on the board
/TimerBorder/DOUT: D36.2 (DOUT); also elsewhere on the board
/TimerBorder/TimerQuadrant/DOUT: D4.4 (DIN); also elsewhere on the board
GND: D4.3 (VSS), D5.3 (VSS), D6.3 (VSS), D7.3 (VSS), D8.3 (VSS), D9.3 (VSS), D10.3 (VSS), D11.3 (VSS), D12.3 (VSS), D13.3 (VSS), D14.3 (VSS), D15.3 (VSS), D16.3 (VSS), D17.3 (VSS), D18.3 (VSS), D19.3 (VSS), D20.3 (VSS), D21.3 (VSS), D22.3 (VSS), D23.3 (VSS), D24.3 (VSS), D25.3 (VSS), D26.3 (VSS), D27.3 (VSS), D28.3 (VSS), D29.3 (VSS), D30.3 (VSS), D31.3 (VSS), D32.3 (VSS), D33.3 (VSS), D34.3 (VSS), D35.3 (VSS), D36.3 (VSS), D37.3 (VSS), D38.3 (VSS); also elsewhere on the board
unnamed: D4.2 (DOUT), D7.4 (DIN)
unnamed: D5.2 (DOUT), D8.4 (DIN)
unnamed: D6.2 (DOUT), D9.4 (DIN)
unnamed: D7.2 (DOUT), D10.4 (DIN)
unnamed: D10.2 (DOUT), D13.4 (DIN)
unnamed: D8.2 (DOUT), D11.4 (DIN)
unnamed: D11.2 (DOUT), D14.4 (DIN)
unnamed: D9.2 (DOUT), D12.4 (DIN)
unnamed: D12.2 (DOUT), D15.4 (DIN)
unnamed: D13.2 (DOUT), D16.4 (DIN)
unnamed: D14.2 (DOUT), D17.4 (DIN)
unnamed: D15.2 (DOUT), D18.4 (DIN)
unnamed: D16.2 (DOUT), D19.4 (DIN)
unnamed: D17.2 (DOUT), D20.4 (DIN)
unnamed: D18.2 (DOUT), D21.4 (DIN)
unnamed: D19.2 (DOUT), D22.4 (DIN)
unnamed: D20.2 (DOUT), D23.4 (DIN)
unnamed: D21.2 (DOUT), D24.4 (DIN)
unnamed: D22.2 (DOUT), D25.4 (DIN)
unnamed: D23.2 (DOUT), D26.4 (DIN)
unnamed: D24.2 (DOUT), D27.4 (DIN)
unnamed: D25.2 (DOUT), D28.4 (DIN)
unnamed: D26.2 (DOUT), D29.4 (DIN)
unnamed: D27.2 (DOUT), D30.4 (DIN)
unnamed: D28.2 (DOUT), D31.4 (DIN)
unnamed: D29.2 (DOUT), D32.4 (DIN)
unnamed: D30.2 (DOUT), D33.4 (DIN)
unnamed: D31.2 (DOUT), D34.4 (DIN)
unnamed: D32.2 (DOUT), D35.4 (DIN)
unnamed: D33.2 (DOUT), D36.4 (DIN)
unnamed: D34.2 (DOUT), D37.4 (DIN)
unnamed: D35.2 (DOUT), D38.4 (DIN)
unnamed: D5.4 (DIN), D37.2 (DOUT)
unnamed: D6.4 (DIN), D38.2 (DOUT)

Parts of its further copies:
D252, D253, D254, D255, D256, D257, D258, D259, D260, D261, D262, D263, D264, D265, D266, D267, D268, D269, D270, D271, D272, D273, D274, D275, D276, D277, D278, D279, D280, D281, D282, D283, D284, D285, D286: WS2812B; LED_WS2812B_PLCC4_5.0x5.0mm_P3.2mm; LCSC C2843785

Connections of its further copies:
+5V: D252.1 (VDD), D253.1 (VDD), D254.1 (VDD), D255.1 (VDD), D256.1 (VDD), D257.1 (VDD), D258.1 (VDD), D259.1 (VDD), D260.1 (VDD), D261.1 (VDD), D262.1 (VDD), D263.1 (VDD), D264.1 (VDD), D265.1 (VDD), D266.1 (VDD), D267.1 (VDD), D268.1 (VDD), D269.1 (VDD), D270.1 (VDD), D271.1 (VDD), D272.1 (VDD), D273.1 (VDD), D274.1 (VDD), D275.1 (VDD), D276.1 (VDD), D277.1 (VDD), D278.1 (VDD), D279.1 (VDD), D280.1 (VDD), D281.1 (VDD), D282.1 (VDD), D283.1 (VDD), D284.1 (VDD), D285.1 (VDD), D286.1 (VDD); also elsewhere on the board
/TimerBorder/TimerQuadrant/DOUT: D284.2 (DOUT); also elsewhere on the board
BORDER_LEDS: D252.4 (DIN); also elsewhere on the board
GND: D252.3 (VSS), D253.3 (VSS), D254.3 (VSS), D255.3 (VSS), D256.3 (VSS), D257.3 (VSS), D258.3 (VSS), D259.3 (VSS), D260.3 (VSS), D261.3 (VSS), D262.3 (VSS), D263.3 (VSS), D264.3 (VSS), D265.3 (VSS), D266.3 (VSS), D267.3 (VSS), D268.3 (VSS), D269.3 (VSS), D270.3 (VSS), D271.3 (VSS), D272.3 (VSS), D273.3 (VSS), D274.3 (VSS), D275.3 (VSS), D276.3 (VSS), D277.3 (VSS), D278.3 (VSS), D279.3 (VSS), D280.3 (VSS), D281.3 (VSS), D282.3 (VSS), D283.3 (VSS), D284.3 (VSS), D285.3 (VSS), D286.3 (VSS); also elsewhere on the board
unnamed: D252.2 (DOUT), D255.4 (DIN)
unnamed: D253.4 (DIN), D285.2 (DOUT)
unnamed: D253.2 (DOUT), D256.4 (DIN)
unnamed: D254.4 (DIN), D286.2 (DOUT)
unnamed: D254.2 (DOUT), D257.4 (DIN)
unnamed: D255.2 (DOUT), D258.4 (DIN)
unnamed: D256.2 (DOUT), D259.4 (DIN)
unnamed: D257.2 (DOUT), D260.4 (DIN)
unnamed: D258.2 (DOUT), D261.4 (DIN)
unnamed: D259.2 (DOUT), D262.4 (DIN)
unnamed: D260.2 (DOUT), D263.4 (DIN)
unnamed: D261.2 (DOUT), D264.4 (DIN)
unnamed: D262.2 (DOUT), D265.4 (DIN)
unnamed: D263.2 (DOUT), D266.4 (DIN)
unnamed: D264.2 (DOUT), D267.4 (DIN)
unnamed: D265.2 (DOUT), D268.4 (DIN)
unnamed: D266.2 (DOUT), D269.4 (DIN)
unnamed: D267.2 (DOUT), D270.4 (DIN)
unnamed: D268.2 (DOUT), D271.4 (DIN)
unnamed: D269.2 (DOUT), D272.4 (DIN)
unnamed: D270.2 (DOUT), D273.4 (DIN)
unnamed: D271.2 (DOUT), D274.4 (DIN)
unnamed: D272.2 (DOUT), D275.4 (DIN)
unnamed: D273.2 (DOUT), D276.4 (DIN)
unnamed: D274.2 (DOUT), D277.4 (DIN)
unnamed: D275.2 (DOUT), D278.4 (DIN)
unnamed: D276.2 (DOUT), D279.4 (DIN)
unnamed: D277.2 (DOUT), D280.4 (DIN)
unnamed: D278.2 (DOUT), D281.4 (DIN)
unnamed: D279.2 (DOUT), D282.4 (DIN)
unnamed: D280.2 (DOUT), D283.4 (DIN)
unnamed: D281.2 (DOUT), D284.4 (DIN)
unnamed: D282.2 (DOUT), D285.4 (DIN)
unnamed: D283.2 (DOUT), D286.4 (DIN)

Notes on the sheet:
35 LEDs per border quadrant



Board: 2 copper layers, 262.2 x 230.0 mm, 223 parts (29 on the bottom side), 200 nets.

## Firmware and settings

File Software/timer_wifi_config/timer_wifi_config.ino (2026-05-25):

#include <WiFi.h>
#include <WebServer.h>
#include <WebSocketsServer.h>
#include <FastLED.h>
#include <Preferences.h>  // Use NVS for WiFi storage
#include "browser.h"

Preferences preferences;
WebServer server(80);
WebSocketsServer webSocket = WebSocketsServer(81);

const char* apSSID = "TimerSetup";
const char* apPassword = "12345678";

bool setupMode = false;

// Pin assignments
#define RESET_BTN 12
#define PAUSE_BTN 14
#define START_BTN 
#define TIME_SEL_SW 13
#define LED_BUILTIN 2
#define BLUE_BTN 16
#define RED_BTN 4

// LED pin assignments and setup
#define DIGIT_PIN   5
#define BORDER_PIN  17
#define DIGIT_LED_COUNT 202
#define BORDER_LED_COUNT 140
#define LEFT_BORDER 0
#define RIGHT_BOARDER 70
#define ORANGE CRGB(255, 50, 0)

CRGB digit_leds[DIGIT_LED_COUNT];
CRGB border_leds[BORDER_LED_COUNT];


int countdown_time = 120; // Default to 2 minutes (120 seconds)
int current_time = countdown_time;
bool is_running = false;
bool lastTimeSelState = false;
bool blueReady = false;
bool redReady = false;
bool preCountdownRunning = false;

bool border_toggle = 1;

// Debounce variables for each button
unsigned long lastDebounceTimeStart = 0;
unsigned long lastDebounceTimePause = 0;
unsigned long lastDebounceTimeReset = 0;
unsigned long lastDebounceTimeTimeSel = 0;
unsigned long lastDebounceTimeBlue = 0;
unsigned long lastDebounceTimeRed = 0;

unsigned long lastCountdownTime = 0;

int countdown = 3; //number of seconds until match start

// Debounce delay (in milliseconds)
unsigned long debounceDelay = 200;

int scrollIndex = 0;
const float scrollInterval = 1000.0 / BORDER_LED_COUNT;  // ~7.14ms per LED
unsigned long lastScrollTime = 0;

void startAPMode() {
    Serial.println("Starting Access Point mode...");
    WiFi.softAP(apSSID, apPassword);
    Serial.print("AP IP Address: ");
    Serial.println(WiFi.softAPIP());
    setupMode = true;
}

void handleRoot() {
  server.send(200, "text/html", html);
}

void handleRoot_AP() {
    server.send(200, "text/html", "<h1>Enter WiFi Credentials</h1><form action='/setwifi' method='post'>SSID: <input name='ssid'><br>Password: <input name='pass' type='password'><br><input type='submit' value='Save'></form>");
}

void handleControl() {
  String cmd = server.arg("cmd");
  if (cmd == "start") {
    starPreCountdown();
  } 
  else if (cmd == "pause") {
    is_running = false;
  } 
  else if (cmd == "reset") {
    is_running = false;
    blueReady = redReady = false;
    current_time = countdown_time;
    setBorder();
    updateClient(); // Update the client immediately
    updateLEDs();
  } 
  else if (cmd == "switch") {
    countdown_time = (countdown_time == 120) ? 180 : 120;
    current_time = countdown_time;
    updateClient(); // Update the client immediately
    updateLEDs();
  }
  server.send(200, "text/plain", "OK");
}

void updateClient() {
  int minutes = current_time / 60;
  int seconds = current_time % 60;
  char buffer[6];
  snprintf(buffer, sizeof(buffer), "%02d:%02d", minutes, seconds);
  webSocket.broadcastTXT(buffer);
}

void updateTimer() {
  unsigned long currentMillis = millis();
  
  if (preCountdownRunning) {
    if (currentMillis - lastScrollTime >= scrollInterval) {
      lastScrollTime = currentMillis;

      // Fill from 0 to scrollIndex with ORANGE
      for (int i = 0; i < BORDER_LED_COUNT; i++) {
        if (i >= scrollIndex) {
          border_leds[i] = ORANGE;
        } 
        else {
          border_leds[i] = CRGB::Black;
        }
      }

      FastLED.show();

      scrollIndex--;
      if (scrollIndex < 0) {
        scrollIndex = BORDER_LED_COUNT - 1;
        countdown--;

        if (countdown <= 0) {
          // countdown is done, start timer
          countdown = 3;
          preCountdownRunning = false;
          scrollIndex = BORDER_LED_COUNT - 1;
          lastCountdownTime = 0;
          lastScrollTime = 0;
          is_running = true;
          lastCountdownTime = millis();

          if (!is_running && current_time == countdown_time) {
            current_time = countdown_time + 1;
          }

          // Set border LEDs
          for (int i = 0; i < BORDER_LED_COUNT/2; i++) {
            border_leds[i] = CRGB::Blue; // First half blue
          }

          // Set border LEDs
          for (int i = BORDER_LED_COUNT/2; i < BORDER_LED_COUNT ; i++) {
            border_leds[i] = CRGB::Red; // Second half red
          }

          FastLED.show(); // Show the initialized border LED colors

          updateClient();
          updateLEDs();
          return; // stop here — don't draw the digit again
        }

        // only draw digit if countdown > 0
        setDigit(0, 0, false);
        setDigit(0, 49, false);
        setColon();
        setDigit(countdown, 101, true);
        setDigit(0, 150, true);
        FastLED.show();
      }
    }
  }

  // Main timer counting down
  if (is_running && current_time > 0) {
    // Countdown every 1 second
    if (currentMillis - lastCountdownTime >= 1000) {
      lastCountdownTime = currentMillis;
      current_time--;
      
      updateClient();  // Reset to 2:00 (or 3:00)
      updateLEDs();
    }
  }
}

void checkButtons() {
  unsigned long currentMillis = millis();

  // Start button
  if (digitalRead(START_BTN) == LOW && currentMillis - lastDebounceTimeStart > debounceDelay) {

    starPreCountdown();
    lastDebounceTimeStart = currentMillis;  // Update debounce time
  }

  // Pause button
  if (digitalRead(PAUSE_BTN) == LOW && currentMillis - lastDebounceTimePause > debounceDelay) {
    is_running = false;
    lastDebounceTimePause = currentMillis;
  }

  // Blue Ready button
  if (digitalRead(BLUE_BTN) == LOW && currentMillis - lastDebounceTimeBlue > debounceDelay) {
    blueReady = true;

    // Set border LEDs
    for (int i = 0; i < BORDER_LED_COUNT/2; i++) {
      border_leds[i] = CRGB::Blue; // First half blue
    }
    FastLED.show(); // Show the initialized border LED colors

    lastDebounceTimePause = currentMillis;
  }

   // Blue Ready button
  if (digitalRead(RED_BTN) == LOW && currentMillis - lastDebounceTimeRed > debounceDelay) {
    redReady = true;

    // Set border LEDs
    for (int i = BORDER_LED_COUNT/2; i < BORDER_LED_COUNT ; i++) {
      border_leds[i] = CRGB::Red; // Second half red
    }
    FastLED.show(); // Show the initialized border LED colors
    
    lastDebounceTimePause = currentMillis;
  }

  // Reset button
  if (digitalRead(RESET_BTN) == LOW && currentMillis - lastDebounceTimeReset > debounceDelay) {
    is_running = false;
    current_time = countdown_time;
    blueReady = false;
    redReady = false;
    setBorder();
    updateClient();
    updateLEDs();
    lastDebounceTimeReset = currentMillis;
  }

  // Time select switch
  bool timeSelState = digitalRead(TIME_SEL_SW) == LOW;
  if (timeSelState != lastTimeSelState && currentMillis - lastDebounceTimeTimeSel > debounceDelay) {
    lastTimeSelState = timeSelState;
    countdown_time = timeSelState ? 180 : 120;
    current_time = countdown_time;
    updateClient();
    updateLEDs();
    lastDebounceTimeTimeSel = currentMillis;
  }
}

void starPreCountdown() {
  if(!is_running && blueReady && redReady) {
      countdown = 3;
      scrollIndex = BORDER_LED_COUNT - 1;
      preCountdownRunning = true; // Initiate the pre-countdown
      // Use ternary operation to set border LEDs to orange or black
      for (int i = 0; i < BORDER_LED_COUNT; i++) {
        border_leds[i] = ORANGE;
      }

      setDigit(0, 0, false);
      setDigit(0, 49, false);
      setColon();
      setDigit(countdown, 101, true);
      setDigit(0, 150, true);

      FastLED.show();
    }
}

void onWebSocketEvent(uint8_t num, WStype_t type, uint8_t * payload, size_t length) {
  // Nothing to do here for now
}

void handleSetWiFi() {
    String ssid = server.arg("ssid");
    String pass = server.arg("pass");
    
    if (ssid.length() > 0 && pass.length() > 0) {
        preferences.begin("wifi", false);
        preferences.putString("ssid", ssid);
        preferences.putString("pass", pass);
        preferences.end();
        
        server.send(200, "text/html", "<h1>WiFi Credentials Saved! Rebooting...</h1>");
        delay(3000);
        ESP.restart();
    } else {
        server.send(200, "text/html", "<h1>Invalid Input</h1>");
    }
}

void connectWiFi() {
    preferences.begin("wifi", true);
    String ssid = preferences.getString("ssid", "");
    String pass = preferences.getString("pass", "");
    preferences.end();
    
    if (ssid.length() == 0) {
        Serial.println("No WiFi credentials stored, starting AP mode...");
        startAPMode();
        return;
    }
    
    Serial.print("Connecting to WiFi: ");
    Serial.println(ssid);
    WiFi.begin(ssid.c_str(), pass.c_str());
    
    unsigned long startAttemptTime = millis();
    while (WiFi.status() != WL_CONNECTED && millis() - startAttemptTime < 30000) {
        Serial.print(".");

        if(border_toggle)
        {
            //turn off LEDs
          for (int i = 0; i < BORDER_LED_COUNT; i++) {
            border_leds[i] = CRGB::Black;  // Turn off all LEDs
          }
          FastLED.show();  // Update LEDs
        }
        else
          setBorder();
        border_toggle = !border_toggle;

        delay(500);
    }

    if (WiFi.status() == WL_CONNECTED) {
        Serial.println("Connected to WiFi!");
        Serial.print("IP Address: ");
        Serial.println(WiFi.localIP());

        server.on("/", handleRoot);
        server.on("/control", handleControl);
        server.begin();

        webSocket.begin();
        webSocket.onEvent(onWebSocketEvent);
    } else {
        Serial.println("Failed to connect, starting AP mode...");
        startAPMode();
    }
}

void setup() {
  Serial.begin(115200);

  // Initialize LED strips
  FastLED.addLeds<NEOPIXEL, DIGIT_PIN>(digit_leds, DIGIT_LED_COUNT);
  FastLED.addLeds<NEOPIXEL, BORDER_PIN>(border_leds, BORDER_LED_COUNT);
  FastLED.setBrightness(255); // Set BRIGHTNESS to max
 
  updateLEDs();//update the text LEDs
  setBorder();//start the border on

  connectWiFi();

  setBorder(); //ensure we leave with border on
  
  if (setupMode) {
      server.on("/", handleRoot_AP);
      server.on("/setwifi", handleSetWiFi);
      server.begin();
  }

  // Set up the buttons and switch pins
  pinMode(RESET_BTN, INPUT_PULLUP);
  pinMode(PAUSE_BTN, INPUT_PULLUP);
  pinMode(START_BTN, INPUT_PULLUP);
  pinMode(TIME_SEL_SW, INPUT_PULLUP);
  pinMode(BLUE_BTN, INPUT_PULLUP);
  pinMode(RED_BTN, INPUT_PULLUP);
  lastTimeSelState = digitalRead(TIME_SEL_SW) == LOW;
  
  // Start the timer update task
  xTaskCreate(
      [](void*) {
          TickType_t lastWakeTime = xTaskGetTickCount();
          while (true) {
              if (is_running || preCountdownRunning) {
                  updateTimer();
              }
              vTaskDelayUntil(&lastWakeTime, pdMS_TO_TICKS(1));
          }
      },
      "TimerTask",
      4096,
      nullptr,
      1,
      nullptr
  );

  // Start the button check task
  xTaskCreate(
      [](void*) {
          while (true) {
              checkButtons();
              vTaskDelay(pdMS_TO_TICKS(50)); // Check buttons every 50ms
          }
      },
      "ButtonCheckTask",
      2048,
      nullptr,
      1,
      nullptr
  );

}


void loop() {
  server.handleClient();
  webSocket.loop();
}

void setDigit(int digit, int offset, bool inverted) {
  static const uint8_t digitMap[10][7] = {
    {1, 1, 1, 1, 1, 1, 0},  // 0
    {0, 1, 1, 0, 0, 0, 0},  // 1
    {1, 1, 0, 1, 1, 0, 1},  // 2
    {1, 1, 1, 1, 0, 0, 1},  // 3
    {0, 1, 1, 0, 0, 1, 1},  // 4
    {1, 0, 1, 1, 0, 1, 1},  // 5
    {1, 0, 1, 1, 1, 1, 1},  // 6
    {1, 1, 1, 0, 0, 0, 0},  // 7
    {1, 1, 1, 1, 1, 1, 1},  // 8
    {1, 1, 1, 1, 0, 1, 1}   // 9
  };

  // Remap segments for inverted digits
  static const uint8_t invertedMap[7] = {3, 4, 5, 0, 1, 2, 6};

  for (int i = 0; i < 7; i++) {
    int segmentIndex = inverted ? invertedMap[i] : i;
    int ledIndex = offset + segmentIndex * 7;
    for (int j = 0; j < 7; j++) {
      if (digitMap[digit][i]) {
        digit_leds[ledIndex + j] = CRGB::Red;  // Red color
      } else {
        digit_leds[ledIndex + j] = CRGB::Black;  // Turn off
      }
    }
  }
}

void setColon() {
  for (int i = 0; i < 3; i++) {
    digit_leds[98 + i] = CRGB::Red;  // Colon dot
    digit_leds[199 + i] = CRGB::Red;  // Colon dot
  }
}

void updateLEDs() {
  int minutes = current_time / 60;
  int seconds = current_time % 60;

  // Convert minutes and seconds to individual digits
  int digit1 = minutes / 10;
  int digit2 = minutes % 10;
  int digit3 = seconds / 10;
  int digit4 = seconds % 10;

  // Update each 7-segment digit and colon dots
  setDigit(digit1, 0, false);     // First digit
  setDigit(digit2, 49, false);    // Second digit
  setColon();                     // Colon dots
  setDigit(digit4, 101, true);    // Third digit (upside down and backwards)
  setDigit(digit3, 150, true);    // Fourth digit (upside down and backwards)

  FastLED.show();  // Update the strip to show the changes
}

void setBorder()
{
  for (int i = 0; i < BORDER_LED_COUNT; i++) {
    border_leds[i].setRGB(127,127,127); //white
  }
 
  FastLED.show(); // Show the initialized border LED colors
}

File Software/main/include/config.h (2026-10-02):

#ifndef CONFIG_H
#define CONFIG_H

#include <Arduino.h>
#include <FastLED.h>
#include <Preferences.h>
#include <time.h>

// Verbose per-event debug logging (every button press, every command, every
// LoRa packet). Controlled by ENABLE_DEBUG_LOG (see platformio.ini) so it
// can be compiled out for quieter/slightly faster event-day builds without
// touching source. Defaults to on, matching prior always-on behavior.
#ifdef ENABLE_DEBUG_LOG
  #define DEBUG_LOG(...) Serial.printf(__VA_ARGS__)
#else
  #define DEBUG_LOG(...)
#endif

// Pin assignments
#define RESET_BTN 15
#define PAUSE_BTN 14
#define START_BTN 27
#define TIME_SEL_SW 13
#define LED_BUILTIN 2
#define BLUE_BTN 4
#define RED_BTN 16
#define BUZZ_PIN 18
#define RELAY_PIN 21

// RA-08H LoRa module (replaces ESP-NOW), see PCB Files/ESP32_Lora netlist.
// UART2: GPIO23 TX (-> module LPRXD), GPIO22 RX (<- module TXD).
#define RADIO_RST_PIN 25
#define RADIO_UART_TX 23
#define RADIO_UART_RX 22
// Hard limit: the module's AT interface runs on its LPUART, which cannot
// exceed 9600 baud. Must match the RA08H_p2p_bridge firmware.
#define RADIO_BAUD 9600

// LED pin assignments
#define DIGIT_PIN   5
#define BORDER_PIN  17
#define DIGIT_LED_COUNT 202
#define BORDER_LED_COUNT 140
#define LEFT_BORDER 0
#define RIGHT_BORDER 70
#define ORANGE CRGB(255, 50, 0)

// Strip calculation constants
#define HALF_DIGIT (DIGIT_LED_COUNT / 2)
#define HALF_BORDER (BORDER_LED_COUNT / 2)
#define PHYSICAL_STRIP_LEN (HALF_DIGIT + HALF_BORDER)

// Double-sided absolute memory buffer requirement
#define DOUBLE_STRIP_LEN (PHYSICAL_STRIP_LEN * 2)

// Add to Config.h
extern CRGB digitColor;
extern uint8_t systemBrightness;

// Global Objects
extern Preferences preferences;

// Defined in main.cpp - pushes an absolute setting value to the configured
// multi-timer sync target (no-op if none is set). Used by timerLogic.cpp's
// "switch" handling: relaying that as a raw toggle command over the sync
// link is fragile (any single missed/guarded application on the peer leaves
// the two timers permanently inverted from then on, since each subsequent
// toggle flips both from an already-diverged base) - pushing the resulting
// absolute time instead is self-correcting the same way every other synced
// setting already is.
extern void pushSyncSetting(const char* type, const String& value);

// Constants
const float scrollInterval = 1000.0 / BORDER_LED_COUNT;
const unsigned long debounceDelay = 200;

// Add these to your "Global Objects" or "Constants" section
extern bool pairingMode;

// redPaired/bluePaired/judgePaired are the UI-facing "is this role bound at
// all" flags (true if bound via LoRa OR ESP-NOW) - recomputed by
// recomputePairedFlags() below any time a path-specific flag changes. Each
// backend validates incoming packets against its OWN path-specific flag
// (e.g. loraRemotes.cpp checks redLoraPaired, never the combined redPaired),
// so a role bound only on one path can't be spoofed by a packet arriving on
// the other, unbound one.
extern bool redPaired, bluePaired, judgePaired;
extern bool redLoraPaired, blueLoraPaired, judgeLoraPaired;
extern bool redEspNowPaired, blueEspNowPaired, judgeEspNowPaired;
void recomputePairedFlags(); // Defined in main.cpp

// Add these to Config.h
extern int current_time;
extern bool readyRequired;

extern int countdown_time;
extern bool blueReady;
extern bool redReady;

extern bool displayInverted;

extern bool tapoutEnabled; // Track if tapouts are allowed during a match
extern bool tapoutInitiatorIsBlue;

extern bool audioEnabled;
extern bool remoteAudioEnabled;
extern uint8_t audioOutputSelect; // 0 = Buzzer (Tone), 1 = Relay (Digital Pin)

// Non-blocking beep engine function prototypes
void triggerBeep(uint32_t durationMs);
void checkAudioTimeout();

enum timerState {
    CONNECTING,
    IDLE,
    PRE_COUNTDOWN_INIT,
    PRE_COUNTDOWN_LOOP,
    RUNNING,
    PAUSED,
    FINISHED,
    CLOCK_MODE, 
    TAPOUT
};

extern int currentState;

// Function prototypes for functions defined in other modules
void starPreCountdown(); // Defined in TimerLogic
void updateClient();     // Defined in Network
void updateLEDs();       // Defined in Display
void setBorder();        // Defined in Display
void queueCommand(const char* cmd); // Defined in main.cpp

// Defined in loraRemotes.cpp
void loraInit();
void loraPoll();
void loraLoadSavedRemotes();

// Defined in espnowRemotes.cpp
void espnowInit();
void espnowLoadSavedRemotes();

// Defined in main.cpp - wipes both backends' pairing state together, since
// the operator-facing "Wipe All" button doesn't (and shouldn't need to) know
// which path a given role was bound through.
void clearRemotes();

#endif

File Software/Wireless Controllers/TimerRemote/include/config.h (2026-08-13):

#ifndef CONFIG_H
#define CONFIG_H

#include <Arduino.h>

// Button GPIOs (STM32G030K6T6, see PCB Files/TimerRemote netlist).
// All buttons are 1:1 GPIO-to-GND, active low, need INPUT_PULLUP.
#define PIN_START PB1
#define PIN_PAUSE PA5
#define PIN_RESET PA6 // also the ReadyRemote's single button
#define PIN_TSEL PA7
#define PIN_BUZZ PB0

// RA-08H control
#define PIN_RADIO_RST PA1
// Hard limit: the module's AT interface runs on its LPUART, which cannot
// exceed 9600 baud. Must match the RA08H_p2p_bridge firmware.
#define RADIO_BAUD 9600
// UART to RA-08H is USART1: PA9 TX (-> module LPRXD), PA10 RX (<- module TXD).
//
// IMPORTANT: this package has two physical pads that can each carry PA9 (and
// likewise for PA10) - the plain, default-location pad, and a second,
// "remapped" pad selectable via the chip's pin-remap feature. Per the actual
// PCB netlist (PCB Files/TimerRemote), the radio is wired to the REMAPPED
// pads, not the default ones - the default PA9/PA10 pads go nowhere (net
// "unconnected-(U2-NC/PA9-Pad19)" etc). Arduino's plain PA9/PA10 macros
// resolve to the default (unconnected) pads, so using them here compiles and
// runs but talks to a floating pin - the radio never receives anything and
// the STM32 never sees a reply, with no error either side. PA_9_R/PA_10_R
// (defined in the STM32duino variant's PinNamesVar.h) are the remap-selected
// PinName values that actually land on the wired pads; HardwareSerial's
// PinName-typed constructor overload is required to use them (the plain
// uint32_t Arduino-pin-number overload can't address a remapped pin).
#define PIN_RADIO_TX PA_9_R
#define PIN_RADIO_RX PA_10_R

// Debug-only, one-way TX broken out to J2 pin 5 (no RX wired)
#define PIN_DEBUG_TX PA2

#endif

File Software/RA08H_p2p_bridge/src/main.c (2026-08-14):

// Bare-bones LoRa <-> host UART bridge for ArenaTimer.
//
// Speaks the same text framing the host code (TimerRemote/src/radio.cpp,
// Software/main/src/loraRemotes.cpp) already implements, so neither host
// file needs to change:
//   host -> radio:  AT+TEST=TXLRPKT,"<HEX>"\n   -> transmits <HEX> over LoRa
//   radio -> host:  +TEST: RXLRPKT,"<HEX>",<rssi>,<snr>\r\n  on packet RX
//
// Runtime-adjustable RF settings, so range/power tuning doesn't need a
// radio reflash - only the (much cheaper to reflash) host MCU needs to send
// its desired config after every boot:
//   host -> radio:  AT+RFCFG=<power>,<sf>,<bw>,<cr>\n
//                     power: -3..22 (dBm, SX1262 max)
//                     sf:    5..12  (spreading factor)
//                     bw:    0..2   (0=125kHz, 1=250kHz, 2=500kHz)
//                     cr:    1..4   (coding rate, 1=4/5 .. 4=4/8)
//   radio -> host:  OK\r\n   or ERROR\r\n if out of range / malformed
//   host -> radio:  AT+RFCFG?\n           -> query current values
//   radio -> host:  +RFCFG: <power>,<sf>,<bw>,<cr>\r\nOK\r\n
//
// RFCFG changes are RAM-only, not persisted in the radio's own flash - they
// reset to the DEFAULT_* values below on every power-up/reset. SF and BW
// must match on both ends of a link or the two radios can't demodulate each
// other's packets; TX power is one-sided and only needs to change on the
// transmitting radio.
//
// Also runtime-adjustable: whether the radio sits in continuous receive or
// sleeps between transmits. A LoRa remote in this system only ever sends
// (button presses) and never needs to receive, so leaving it in continuous
// RX - the SX1262's most power-hungry state - burns battery for no reason.
// The timer, which must always be listening, needs the opposite:
//   host -> radio:  AT+RXMODE=<mode>\n
//                     mode: 0 = TX-only (sleep between sends - remotes)
//                           1 = continuous RX (default - the timer)
//   radio -> host:  OK\r\n   or ERROR\r\n if out of range
//   host -> radio:  AT+RXMODE?\n
//   radio -> host:  +RXMODE: <mode>\r\nOK\r\n
// Waking from Sleep() to transmit needs no special handling: any SPI
// transaction wakes the SX1262 automatically (a documented hardware
// feature), and this firmware already relies on that exact Sleep()->next
// action transition after every completed TX (see OnTxDone below).
//
// Runs identically on both the remote and timer boards - which side is
// "remote" vs "timer" is entirely a host-MCU concern, not a radio concern.
//
// UART pins match the board's actual wiring (see PCB Files netlists):
//   LPUART RX  = GPIOD pin 12 (GP60 / LPRXD/IO60) - host's TX arrives here
//   UART0  TX  = GPIOB pin 1  (GP17 / TXD/IO17)    - shared with the debug/
//                                                     flash port, but only
//                                                     TX is used here

#include <stdio.h>
#include <string.h>
#include <stdbool.h>
#include "delay.h"
#include "timer.h"
#include "radio.h"
#include "tremo_system.h"
#include "tremo_uart.h"
#include "tremo_lpuart.h"
#include "tremo_gpio.h"
#include "tremo_rcc.h"
#include "tremo_pwr.h"
#include "tremo_delay.h"
#include "rtc-board.h"

#if defined( REGION_US915 )
#define RF_FREQUENCY 915000000
#else
#error "Build with -DREGION_US915"
#endif

// Power-on defaults - overridden at runtime by AT+RFCFG (see header comment).
#define DEFAULT_TX_OUTPUT_POWER       14
#define DEFAULT_LORA_BANDWIDTH        0 // 125 kHz
#define DEFAULT_LORA_SPREADING_FACTOR 7
#define DEFAULT_LORA_CODINGRATE       1 // 4/5

#define LORA_PREAMBLE_LENGTH         8
#define LORA_SYMBOL_TIMEOUT          0
#define LORA_FIX_LENGTH_PAYLOAD_ON   false
#define LORA_IQ_INVERSION_ON         false
#define RX_TIMEOUT_VALUE             5000 // ms, re-armed on every timeout

#define RFCFG_POWER_MIN  (-3)
#define RFCFG_POWER_MAX  22
#define RFCFG_SF_MIN     5
#define RFCFG_SF_MAX     12
#define RFCFG_BW_MIN     0
#define RFCFG_BW_MAX     2
#define RFCFG_CR_MIN     1
#define RFCFG_CR_MAX     4

// AT+RXMODE values - see header comment.
#define RXMODE_TX_ONLY      0
#define RXMODE_CONTINUOUS   1
#define DEFAULT_RX_MODE     RXMODE_CONTINUOUS

// Bridge UART baud - proven reliable on this LPUART peripheral empirically
// (the stock AT firmware also caps out around here; 115200 is not safe on
// this peripheral, see project memory: RA-08H firmware uncertainty).
#define BRIDGE_BAUD 9600

#define MAX_PAYLOAD 32
#define CMD_BUF_LEN 96

static RadioEvents_t RadioEvents;

// Live RF config, RAM-only (see AT+RFCFG in the header comment).
static int8_t  currentPower = DEFAULT_TX_OUTPUT_POWER;
static uint8_t currentSF    = DEFAULT_LORA_SPREADING_FACTOR;
static uint8_t currentBW    = DEFAULT_LORA_BANDWIDTH;
static uint8_t currentCR    = DEFAULT_LORA_CODINGRATE;
static uint8_t currentRxMode = DEFAULT_RX_MODE;

static uint8_t RxPayload[MAX_PAYLOAD];
static uint16_t RxPayloadSize = 0;
static volatile bool RxPending = false;
static int16_t LastRssi = 0;
static int8_t LastSnr = 0;

static const char HEX_DIGITS[] = "0123456789ABCDEF";

static void hexEncode(const uint8_t* data, uint16_t len, char* out)
{
    for (uint16_t i = 0; i < len; i++) {
        out[i * 2]     = HEX_DIGITS[(data[i] >> 4) & 0xF];
        out[i * 2 + 1] = HEX_DIGITS[data[i] & 0xF];
    }
    out[len * 2] = '\0';
}

static int hexNibble(char c)
{
    if (c >= '0' && c <= '9') return c - '0';
    if (c >= 'A' && c <= 'F') return c - 'A' + 10;
    if (c >= 'a' && c <= 'f') return c - 'a' + 10;
    return -1;
}

static bool hexDecode(const char* hex, uint16_t hexLen, uint8_t* out, uint16_t* outLen)
{
    if (hexLen == 0 || (hexLen % 2) != 0) return false;
    uint16_t n = hexLen / 2;
    if (n > MAX_PAYLOAD) return false;
    for (uint16_t i = 0; i < n; i++) {
        int hi = hexNibble(hex[i * 2]);
        int lo = hexNibble(hex[i * 2 + 1]);
        if (hi < 0 || lo < 0) return false;
        out[i] = (uint8_t)((hi << 4) | lo);
    }
    *outLen = n;
    return true;
}

// Re-arms continuous receive if that's the configured mode, otherwise sleeps
// instead - see AT+RXMODE in the header comment. Called after every TX/RX
// completion or timeout in place of an unconditional Radio.Rx().
static void rearmOrSleep(void)
{
    if (currentRxMode == RXMODE_CONTINUOUS) {
        Radio.Rx(RX_TIMEOUT_VALUE);
    } else {
        Radio.Sleep();
    }
}

void OnTxDone(void)
{
    Radio.Sleep();
    rearmOrSleep();
}

void OnRxDone(uint8_t* payload, uint16_t size, int16_t rssi, int8_t snr)
{
    Radio.Sleep();
    if (size <= MAX_PAYLOAD) {
        memcpy(RxPayload, payload, size);
        RxPayloadSize = size;
        LastRssi = rssi;
        LastSnr = snr;
        RxPending = true;
    }
    rearmOrSleep();
}

void OnTxTimeout(void)
{
    Radio.Sleep();
    rearmOrSleep();
}

void OnRxTimeout(void)
{
    rearmOrSleep();
}

void OnRxError(void)
{
    rearmOrSleep();
}
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

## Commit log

2026-04-30 implement wireless remotes and controllers with roles
2026-04-30 integrate ESPNOW control into full timer code
2026-05-11 implement webpage lockouts for different modes to prevent issues during match
    [timerLogic.cpp]
2026-05-11 push updated remote code that was missing from last commit
    [controller.ino]
2026-05-11 add LED brightness and digit color control
2026-05-11 improve controller sucess rate by transmitting more packets, clean up timer state transition conditions
2026-05-11 added flipped mode support for alternate mounting configs
    [config.h, timerLogic.cpp]
2026-05-25 update board for next order
    [ArenaTimer.kicad_pcb, ArenaTimer.kicad_sch, TimerBorder.kicad_sch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]
2026-05-25 rename some folders
    [ArenaTimer.kicad_pcb, ArenaTimer.kicad_sch, TimerBorder.kicad_sch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]
2026-05-25 Permanently delete duplicate folder structure
    [ArenaTimer.kicad_pcb, ArenaTimer.kicad_sch, TimerBorder.kicad_sch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]
2026-05-25 update silk
    [ArenaTimer.kicad_pcb]
2026-05-25 flip BOUT/DOUT which is techncially flipped, but consistent with legacy HW.
    [ArenaTimer.kicad_sch]
2026-05-26 clean up silk, resolve DRCs
    [ArenaTimer.kicad_pcb, ArenaTimer.kicad_sch]
2026-05-27 more cleanup, added spare IO and power pads for expansion
    [ArenaTimer.kicad_pcb, ArenaTimer.kicad_sch]
2026-05-28 add beeper, generate production files
    [ArenaTimer.kicad_pcb, ArenaTimer.kicad_sch, bom.csv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]
2026-05-28 update controller board to include esp8266
    [ButtonBoard.kicad_pcb, ButtonBoard.kicad_sch]
2026-05-30 finish controller board and prod files
    [ButtonBoard.kicad_pcb, ButtonBoard.kicad_sch, bom.csv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]
2026-05-30 finish ready button board and prod files
    [ReadyButtonBoard.kicad_pcb, ReadyButtonBoard.kicad_sch, bom.csv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]
2026-06-02 fix diode MPN
    [ArenaTimer.kicad_sch]
2026-06-04 update LCSC PN for fets to match sc-70 footprint on board
    [ArenaTimer.kicad_pcb, ArenaTimer.kicad_sch]
2026-06-10 export new 3d models of boards
    [.step, Bottom_left.stl, Bottom_left_lens.stl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]
2026-06-21 update 3d model exports
    [.step, ButtonBoard.step, ReadyButtonBoard.step]
2026-06-26 add web control for remote buzzer control
    [config.h]
2026-06-26 fix clock mode behavior and graphics
    [timerLogic.cpp]
2026-06-28 fix reset bug, fix bound remote check bug
    [controller.ino, timerLogic.cpp]
2026-06-28 set up serial implementation of timer side B
2026-06-29 fixed countdown display glitch
    [timerLogic.cpp]
2026-07-01 kind of stable, still random issues
    [timerLogic.cpp]
2026-07-02 fix all graphical issues by switching all handling to single core, add web update support
    [partitions.csv]
2026-07-31 add new lora remote board
    [Controller_bom.csv, Controller_designators.csv, Controller_positions.csv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]
2026-08-02 add esp32 lora board files
    [ESP32_Lora.kicad_pcb, ESP32_Lora.kicad_sch, bom.csv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]
2026-08-08 convert project to platform IO with claude
    [partitions.csv]
2026-08-12 change RADIO_RST pin to avoid conflict, change 100nF EN cap to 10uF to slow rise time for more stability
    [ESP32_Lora.kicad_sch]
2026-08-13 get radios working and some other schematic changes in for next rev
    [TimerRemote.kicad_sch]
2026-08-14 add rf config AT commands for idle power optimizations
2026-08-14 fix doot display glitch
    [main.cpp, timerLogic.cpp]
2026-08-24 add network reconnect logic and properly gate LED updates to prevent noise in pixel data
    [main.cpp, timerLogic.cpp]
2026-08-26 add multi-timer webpage sync, several other web features/improvements
2026-10-02 Support ESP-NOW and LoRa remotes concurrently in one firmware image
    Lets a timer bind, e.g., Red to an old ESP-NOW remote and Blue to a new
    LoRa one at the same time, so the new LoRa-capable board can be deployed
    before every remote in the field is replaced. One PlatformIO
    environment, both backends compiled in, gated at runtime rather than
    build time - simplest for users, and avoids the "flashed the wrong
    binary onto the wrong hardware" risk entirely.
    Core backend work:
    - New espnowRemotes.cpp/h, mirroring loraRemotes.h's shape, routed
    through the same queueCommand() pipeline LoRa already uses.
    - Pairing flags split into *LoraPaired / *EspNowPaired per role, with a
    combined redPaired/b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
    [config.h, controller.ino, espnowRemotes.cpp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]
2026-10-02 Restructure Judge ESP-NOW remote (controller.ino) as a PlatformIO project
    Pure move - zero logic changes, verified by diff against the original
    (the only difference was the Arduino IDE auto-moving it into a same-
    named subfolder when opened, which changed line endings to CRLF but
    not content - also diff-confirmed). Board (espressif8266/d1_mini)
    inferred from sibling projects in this same remote hardware batch:
    drive_ready_remote's old ESP-NOW build committed FQBN
    esp8266.esp8266.d1, and LoraReadyButton targeted d1_mini directly -
    confirmed correct, build succeeds against it.
    No prior committed binary existed for this file to hash-compare
    against (unlike the timer firmware's restructuring),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
    [main.cpp]
2026-10-02 Give each ESP-NOW remote its own PlatformIO project folder
    controller.ino's restructuring landed directly under ESPNOW_Remote/
    earlier, but that only works for one firmware target - ready_remote
    (the Red/Blue driver-ready remote, recovered from git history) is a
    genuinely separate source file for a separate physical device, not a
    DEV_TYPE-configurable variant of the same one. Moved controller into
    its own controller/ subfolder and added ready_remote/ alongside it,
    each with its own platformio.ini (same espressif8266/d1_mini board)
    and .gitignore.
    Also fixes a stale README claim from before ready_remote.ino was
    actually recovered and inspected - it is not 'one shared source' with
    controller.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
    [main.cpp]
2026-10-02 Fix stale shared-source claim in Wireless Controllers README
    controller.ino and ready_remote.ino are genuinely separate source files for separate physical devices, not DEV_TYPE-configurable variants of one shared template - that assumption got corrected once ready_remote.ino was actually recovered from git history and inspected. Updated to reflect both now being their own PlatformIO projects.
2026-10-22 Add experimental RCE Manager hardware-timer integration
    The timer can join an RCE Manager arena as a hardware device (live
    connection + timer control, v1): RCE Manager's start/pause/reset/adjust
    drive the display, and the timer's own controls (web page, Judge remote)
    drive RCE Manager's clock. If the organizer assigns the timer as the clock
    authority, its time is the reference.
    Opt-in: "RCE mode" is just an integration key plus an arena name entered in
    a new RCE Manager box on the web page. With neither set, none of this runs.
    In RCE mode (RCE Manager has no equivalent of these):
    - the 3-2-1 pre-countdown, tapouts, driver-ready, the 2/3m switch and web
    time entry are disabled, and the bo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
